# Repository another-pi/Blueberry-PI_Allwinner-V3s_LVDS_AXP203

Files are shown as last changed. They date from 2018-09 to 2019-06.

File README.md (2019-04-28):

main build board now is `Blueberry Pi 7.1.2.esp32.no-lan.gsm-a9g`. because `a9g` gsm module is much better then `sim800c`. because of open source SDK and support of GPS.

but still work-in-progress. not finished.

sources of Linux kernel (4.10.15) for this board(s). preconfigured:
https://github.com/bhgv/linux

precompiled Linux-4.10.15 SD-image with support of fb-graphics an resistive touch:
https://github.com/bhgv/linux/releases/tag/1.0a

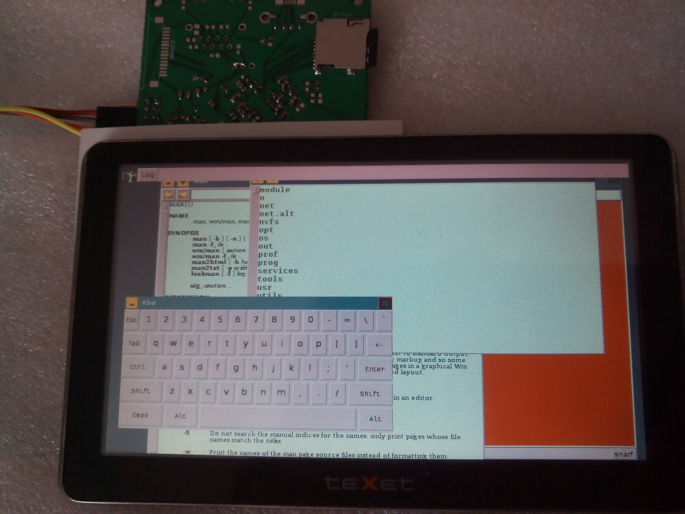
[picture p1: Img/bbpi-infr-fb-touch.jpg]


Blueberry Pi 7.1.2.esp32.no-lan
===============================
(not finished yet)
* removed lan port,
* added 50pins fpc RGB connector for popular 7" tfts (AT070TN[90, 91, 92, 93, 94]) in parallel to 40pins one,
* connector for capacitive touchscreens (i2c1),
* power converters for 50pins socket,
* 25% smaller board.
* esp32 now wired as wifi/bluetooth and as io expander-coprocessor.

Blueberry Pi 7.1.1+ESP32-S
==========================
(not finised yet)
* other power controller(s). 3 cheap and easy to solder chips in sot23-6,
* a try to use ESP32-S module as a WiFi/Bluetooth co-processor.

List of compatible (and cheap) LCDs (with touchscreens)
=======================================================
* ? 7" -- MDT7000
* 7" -- TKR7040B
* 7" -- GL070009T0-40

* 6" -- KD060G1-40nc-a5
* 6" -- TM060RDH02

* 5" -- HSD050IDW1-A20
* 5" -- MH0506D
* 5" -- KD50G21-40NT-A1
* 5" -- A26TF9C032169 * A0 -A20
* 5" -- H-H050L-12M
* 5" -- GL050001C0-40
* 5" -- ft050s800480005n-v01
* 5" -- HW800480F-0F-0L-20
* 5" -- hw800480f-0f-0l-10
* 5" -- T050SWV012T
* 5" -- T050SWV015T
* 5" -- FC050S151-01
* 5" -- KD50G23-40NB-A1
* 5" -- HLY050ML115-12A

(
* 6" -- texet tn-811bt

* 5" --
- Window N5 TOP Tablet PC/ N5PRO/ Onda 580
- TeXet T-939HD
- TeXet T-930HD
- TeXet TN-550A
- TeXet TN-511HD
- TeXet TN-521HD
- TeXet TN-610HD
- TeXet TN-611HD
- TeXet TM-650 (100%)
- Explay PN-955
- Explay PN-960
- SHTURMANN Play 500
- IQU Smile
- Lexand Si-515 Pro HD
- Lexand SG-615 PRO HD
- Ritmix
- EasyGo 500Bi (100%)
- lexand str-5350 hd (100%)
- Prestigio Geovision 5500BTFMHD (100%)
- Prestigio GeoVision 5600GPRSHD
- Explay SLK5
- JXD S5300
- TurboGames New
- EXEQ SET
)

Blueberry Pi 7.1+axp203
=======================
is the Blueberry Pi 7.1 board but with AXP203 power controller, not EA3036. and has DC-DC step down (5-12v) on power input.

Blueberry PI 7.1
================

Added:
------
* LVDS interface with cheap SN65LVDS84 serialiser,
* resistive touchscreen controller TSC2003 + pinheader for resistive touch,
* flash w25q128,
* more popular MicroSD card slot,
* datasheets for them

Removed:
--------
* pinheader for OV7670

Blueberry PI
============
Another fruit single board computer (SBC), based on the Allwinner V3s system on a chip (SOC).
The Allwinner V3s comes in an easy to solder 128pin TQFP package.

The Blueberry PI features:

- 100 mbps Ethernet
- 1 USB Host Port / 1 mini USB port
- MIPI CSI interface (unfortunately no support in the linux kernel yet)
- Pinheader for an OV2640 and an OV7670
- Wifi and bluetooth
- RGB interface for connecting displays
- Audio jack
- an onboard microphone
- four buttons for play, pause, next and previous
- a Raspberry PI compatible header
- SPI Flash
- SD card slot

The Blueberry PI can boot from an SD card or SPI Flash.
Since the V3s doesn't have a standard video output, I'm planning on creating a video addon board which provides VGA or HDMI. In combination with the ADV7611 it is possible to capture HDMI.

If you have any questions email me at marcel[dot]thuermer(at)smail[dot]emt[dot]h[minus]brs[dot]de

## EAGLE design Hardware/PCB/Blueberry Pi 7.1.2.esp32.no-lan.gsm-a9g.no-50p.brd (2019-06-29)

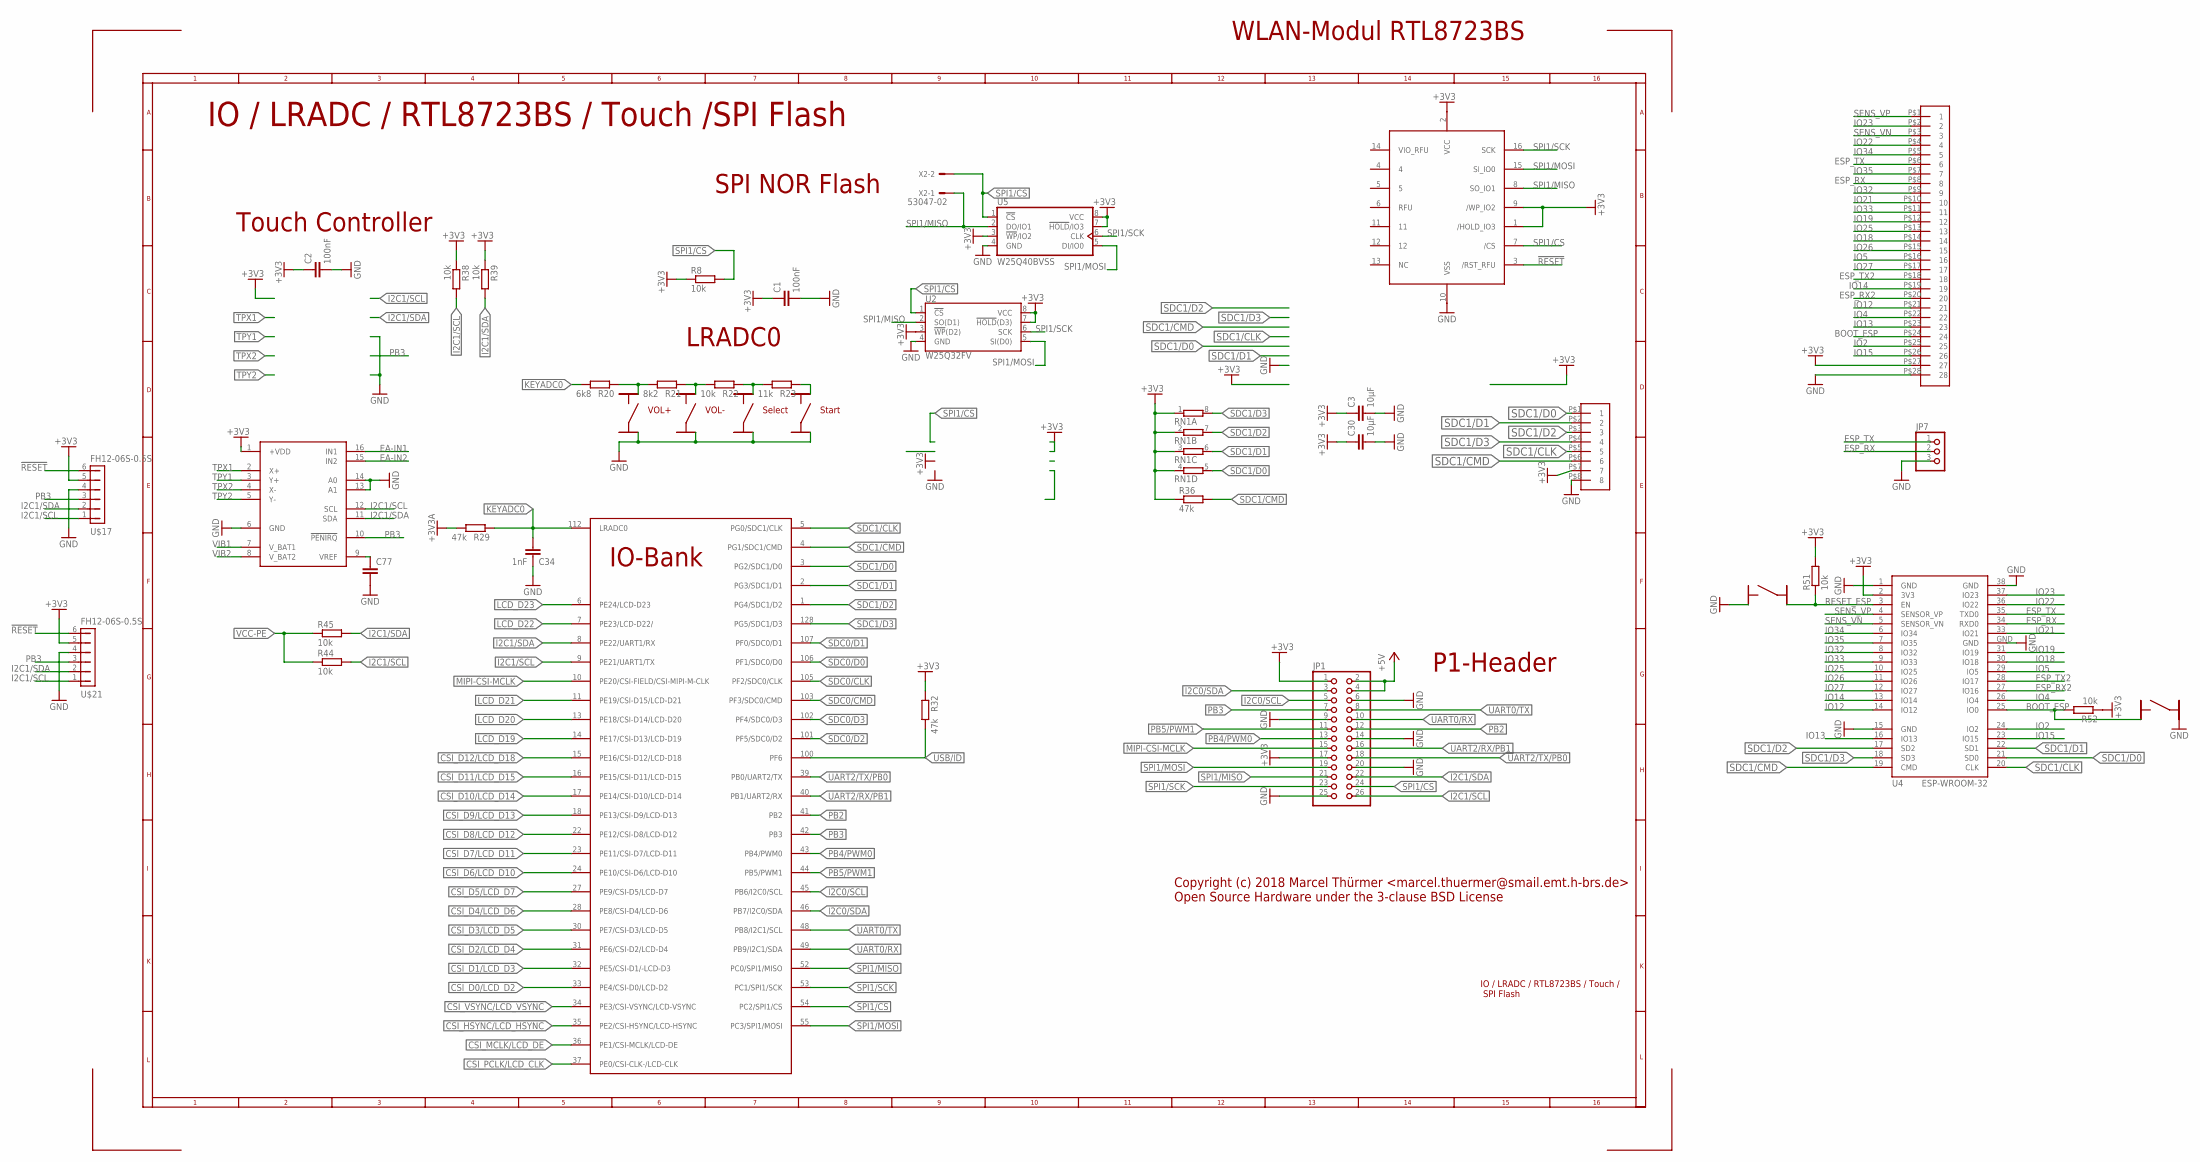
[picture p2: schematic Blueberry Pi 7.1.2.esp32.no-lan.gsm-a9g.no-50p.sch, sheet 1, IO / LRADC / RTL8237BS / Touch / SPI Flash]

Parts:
C1, C2: 100nF; C0603
C3, C30: 10µF; C0805
C34: 1nF; C0603
C77: C-EUC0603; C0603
JP1: PINHD-2X13; 2X13
JP7: PINHD-1X3M; 1X03M
R8, R22, R38, R39, R44, R45, R51, R52: 10k; R0603
R20: 6k8; R0603
R21: 8k2; R0603
R23: 11k; R0603
R29, R32, R36: 47k; R0603
RN1: 4R-NEXB38V; EXB38V
S-BOOT-ESP: BUTTON_3X3MM_4PINS; BUT_3X3_4PINS
S-RST-ESP: BUTTON_3X3MM_4PINS; BUT_3X3_4PINS
S-SEL: BUTTON_3X3MM_4PINS; BUT_3X3_4PINS
S-START: BUTTON_3X3MM_4PINS; BUT_3X3_4PINS
S-VOL+: BUTTON_3X3MM_4PINS; BUT_3X3_4PINS
S-VOL-: BUTTON_3X3MM_4PINS; BUT_3X3_4PINS
U2: W25Q32FV; WSON8-6X5MM
U4: ESP-WROOM-32
U5: W25Q40BVSS; SO08-SS
U$1: V3S; QFP-128
U$3: HDR-1.27MM-142; HDR-1.27MM-19*2
U$4: HDR-1.27MM-42; HDR-1.27MM-4*2
U$7: TSC2003; TSSOP16
U$16: S25FL256S; WSOIC-16
U$17, U$21: FH12-06S-0.5S; FH12-6S-0.5SH
X2: 53047-02

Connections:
!RESET: U$16.3 (/RST_RFU), U$17.6, U$21.6; also elsewhere on the board
+3V3: C1.1, C2.1, C3.1, C30.1, JP1.1, JP1.17, R8.1, R32.1, R36.1, R38.1, R39.1, R51.2, R52.1, RN1.1, RN1.2 (1), RN1.3 (1), RN1.4 (1), U2.3 (!WP!(D2)), U2.7 (!HOLD!(D3)), U2.8 (VCC), U4.2 (3V3), U5.3 (!WP!/IO2), U5.7 (!HOLD!/IO3), U5.8 (VCC), U$3.P$27 (27), U$4.P$7 (7), U$7.1 (+VDD), U$16.1 (/HOLD_IO3), U$16.2 (VCC), U$16.9 (/WP_IO2), U$17.5, U$21.5; also elsewhere on the board
+3V3A: R29.2; also elsewhere on the board
+5V: JP1.2, JP1.4; also elsewhere on the board
BOOT_ESP: R52.2, S-BOOT-ESP.P$1, U4.25 (IO0), U$3.P$24 (24)
CSI_D0/LCD_D2: U$1.33 (PE4/CSI-D0/LCD-D2); also elsewhere on the board
CSI_D1/LCD_D3: U$1.32 (PE5/CSI-D1/-LCD-D3); also elsewhere on the board
CSI_D2/LCD_D4: U$1.31 (PE6/CSI-D2/LCD-D4); also elsewhere on the board
CSI_D3/LCD_D5: U$1.30 (PE7/CSI-D3/LCD-D5); also elsewhere on the board
CSI_D4/LCD_D6: U$1.28 (PE8/CSI-D4/LCD-D6); also elsewhere on the board
CSI_D5/LCD_D7: U$1.27 (PE9/CSI-D5/LCD-D7); also elsewhere on the board
CSI_D6/LCD_D10: U$1.24 (PE10/CSI-D6/LCD-D10); also elsewhere on the board
CSI_D7/LCD_D11: U$1.23 (PE11/CSI-D7/LCD-D11); also elsewhere on the board
CSI_D8/LCD_D12: U$1.22 (PE12/CSI-D8/LCD-D12); also elsewhere on the board
CSI_D9/LCD_D13: U$1.18 (PE13/CSI-D9/LCD-D13); also elsewhere on the board
CSI_D10/LCD_D14: U$1.17 (PE14/CSI-D10/LCD-D14); also elsewhere on the board
CSI_D11/LCD_D15: U$1.16 (PE15/CSI-D11/LCD-D15); also elsewhere on the board
CSI_D12/LCD_D18: U$1.15 (PE16/CSI-D12/LCD-D18); also elsewhere on the board
CSI_HSYNC/LCD_HSYNC: U$1.35 (PE2/CSI-HSYNC/LCD-HSYNC); also elsewhere on the board
CSI_MCLK/LCD_DE: U$1.36 (PE1/CSI-MCLK/LCD-DE); also elsewhere on the board
CSI_PCLK/LCD_CLK: U$1.37 (PE0/CSI-CLK-/LCD-CLK); also elsewhere on the board
CSI_VSYNC/LCD_VSYNC: U$1.34 (PE3/CSI-VSYNC/LCD-VSYNC); also elsewhere on the board
EA-IN1: U$7.16 (IN1); also elsewhere on the board
EA-IN2: U$7.15 (IN2); also elsewhere on the board
ESP_RX: JP7.2, U4.34 (RXD0), U$3.P$8 (8)
ESP_RX2: U4.27 (IO16), U$3.P$20 (20); also elsewhere on the board
ESP_TX: JP7.1, U4.35 (TXD0), U$3.P$6 (6)
ESP_TX2: U4.28 (IO17), U$3.P$18 (18); also elsewhere on the board
GND: C1.2, C2.2, C3.2, C30.2, C34.1, C77.2, JP1.6, JP1.9, JP1.14, JP1.20, JP1.25, JP7.3, S-BOOT-ESP.P$2, S-RST-ESP.P$1, S-SEL.P$4, S-START.P$4, S-VOL+.P$4, S-VOL-.P$4, U2.4 (GND), U4.1 (GND), U4.15 (GND), U4.38 (GND), U4.GND, U5.4 (GND), U$3.P$28 (28), U$4.P$8 (8), U$7.6 (GND), U$7.13 (A1), U$7.14 (A0), U$16.10 (VSS), U$17.4, U$21.4; also elsewhere on the board
I2C0/SCL: JP1.5, U$1.45 (PB6/I2C0/SCL)
I2C0/SDA: JP1.3, U$1.46 (PB7/I2C0/SDA)
I2C1/SCL: JP1.26, R38.2, R44.2, U$1.9 (PE21/UART1/TX), U$7.12 (SCL), U$17.1, U$21.1; also elsewhere on the board
I2C1/SDA: JP1.22, R39.2, R45.2, U$1.8 (PE22/UART1/RX), U$7.11 (SDA), U$17.2, U$21.2; also elsewhere on the board
IO2: U4.24 (IO2), U$3.P$25 (25)
IO4: U4.26 (IO4), U$3.P$22 (22)
IO5: U4.29 (IO5), U$3.P$16 (16)
IO12: U4.14 (IO12), U$3.P$21 (21)
IO13: U4.16 (IO13), U$3.P$23 (23)
IO14: U4.13 (IO14), U$3.P$19 (19); also elsewhere on the board
IO15: U4.23 (IO15), U$3.P$26 (26)
IO18: U4.30 (IO18), U$3.P$14 (14)
IO19: U4.31 (IO19), U$3.P$12 (12)
IO21: U4.33 (IO21), U$3.P$10 (10)
IO22: U4.36 (IO22), U$3.P$4 (4)
IO23: U4.37 (IO23), U$3.P$2 (2)
IO25: U4.10 (IO25), U$3.P$13 (13)
IO26: U4.11 (IO26), U$3.P$15 (15)
IO27: U4.12 (IO27), U$3.P$17 (17); also elsewhere on the board
IO32: U4.8 (IO32), U$3.P$9 (9)
IO33: U4.9 (IO33), U$3.P$11 (11)
IO34: U4.6 (IO34), U$3.P$5 (5)
IO35: U4.7 (IO35), U$3.P$7 (7)
KEYADC0: C34.2, R20.2, R29.1, U$1.112 (LRADC0)
LCD_D19: U$1.14 (PE17/CSI-D13/LCD-D19); also elsewhere on the board
LCD_D20: U$1.13 (PE18/CSI-D14/LCD-D20); also elsewhere on the board
LCD_D21: U$1.11 (PE19/CSI-D15/LCD-D21); also elsewhere on the board
LCD_D22: U$1.7 (PE23/LCD-D22/); also elsewhere on the board
LCD_D23: U$1.6 (PE24/LCD-D23); also elsewhere on the board
MIPI-CSI-MCLK: JP1.15, U$1.10 (PE20/CSI-FIELD/CSI-MIPI-M-CLK); also elsewhere on the board
unnamed: R20.1, R21.2, S-VOL+.P$3
unnamed: C77.1, U$7.9 (VREF)
unnamed: R21.1, R22.2, S-VOL-.P$3
unnamed: R22.1, R23.2, S-SEL.P$3
unnamed: R23.1, S-START.P$3
PB2: JP1.12, U$1.41 (PB2); also elsewhere on the board
PB3: JP1.7, U$1.42 (PB3), U$7.10 (!PENIRQ), U$17.3, U$21.3; also elsewhere on the board
PB4/PWM0: JP1.13, U$1.43 (PB4/PWM0); also elsewhere on the board
PB5/PWM1: JP1.11, U$1.44 (PB5/PWM1); also elsewhere on the board
RESET_ESP: R51.1, S-RST-ESP.P$2, U4.3 (EN)
SDC0/CLK: U$1.105 (PF2/SDC0/CLK); also elsewhere on the board
SDC0/CMD: U$1.103 (PF3/SDC0/CMD); also elsewhere on the board
SDC0/D0: U$1.106 (PF1/SDC0/D0); also elsewhere on the board
SDC0/D1: U$1.107 (PF0/SDC0/D1); also elsewhere on the board
SDC0/D2: U$1.101 (PF5/SDC0/D2); also elsewhere on the board
SDC0/D3: U$1.102 (PF4/SDC0/D3); also elsewhere on the board
SDC1/CLK: U4.20 (CLK), U$1.5 (PG0/SDC1/CLK), U$4.P$5 (5)
SDC1/CMD: R36.2, U4.19 (CMD), U$1.4 (PG1/SDC1/CMD), U$4.P$6 (6)
SDC1/D0: RN1.5 (2), U4.21 (SD0), U$1.3 (PG2/SDC1/D0), U$4.P$1 (1)
SDC1/D1: RN1.6 (2), U4.22 (SD1), U$1.2 (PG3/SDC1/D1), U$4.P$2 (2)
SDC1/D2: RN1.7 (2), U4.17 (SD2), U$1.1 (PG4/SDC1/D2), U$4.P$3 (3)
SDC1/D3: RN1.8 (2), U4.18 (SD3), U$1.128 (PG5/SDC1/D3), U$4.P$4 (4)
SENS_VN: U4.5 (SENSOR_VN), U$3.P$3 (3)
SENS_VP: U4.4 (SENSOR_VP), U$3.P$1 (1)
SPI1/CS: JP1.24, R8.2, U2.1 (!CS!), U5.1 (!CS!), U$1.54 (PC2/SPI1/CS), U$16.7 (/CS), X2.2
SPI1/MISO: JP1.21, U2.2 (SO(D1)), U5.2 (DO/IO1), U$1.52 (PC0/SPI1/MISO), U$16.8 (SO_IO1), X2.1
SPI1/MOSI: JP1.19, U2.5 (SI(D0)), U5.5 (DI/IO0), U$1.55 (PC3/SPI1/MOSI), U$16.15 (SI_IO0)
SPI1/SCK: JP1.23, U2.6 (SCK), U5.6 (CLK), U$1.53 (PC1/SPI1/SCK), U$16.16 (SCK)
TPX1: U$7.2 (X+); also elsewhere on the board
TPX2: U$7.4 (X-); also elsewhere on the board
TPY1: U$7.3 (Y+); also elsewhere on the board
TPY2: U$7.5 (Y-); also elsewhere on the board
UART0/RX: JP1.10, U$1.49 (PB9/I2C1/SDA)
UART0/TX: JP1.8, U$1.48 (PB8/I2C1/SCL)
UART2/RX/PB1: JP1.16, U$1.40 (PB1/UART2/RX); also elsewhere on the board
UART2/TX/PB0: JP1.18, U$1.39 (PB0/UART2/TX); also elsewhere on the board
USB/ID: R32.2, U$1.100 (PF6); also elsewhere on the board
VCC-PE: R44.1, R45.1
VIB1: U$7.7 (V_BAT1); also elsewhere on the board
VIB2: U$7.8 (V_BAT2); also elsewhere on the board

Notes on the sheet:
IO / LRADC / RTL8723BS / Touch / SPI Flash
Copyright (c) 2018 Marcel Thürmer <marcel.thuermer@smail.emt.h-brs.de> Open Source Hardware under the 3-clause BSD License
SPI NOR Flash
WLAN-Modul RTL8723BS
P1-Header
LRADC0
Start
Select
VOL-
VOL+
Touch Controller
IO / LRADC / RTL8723BS / Touch /SPI Flash

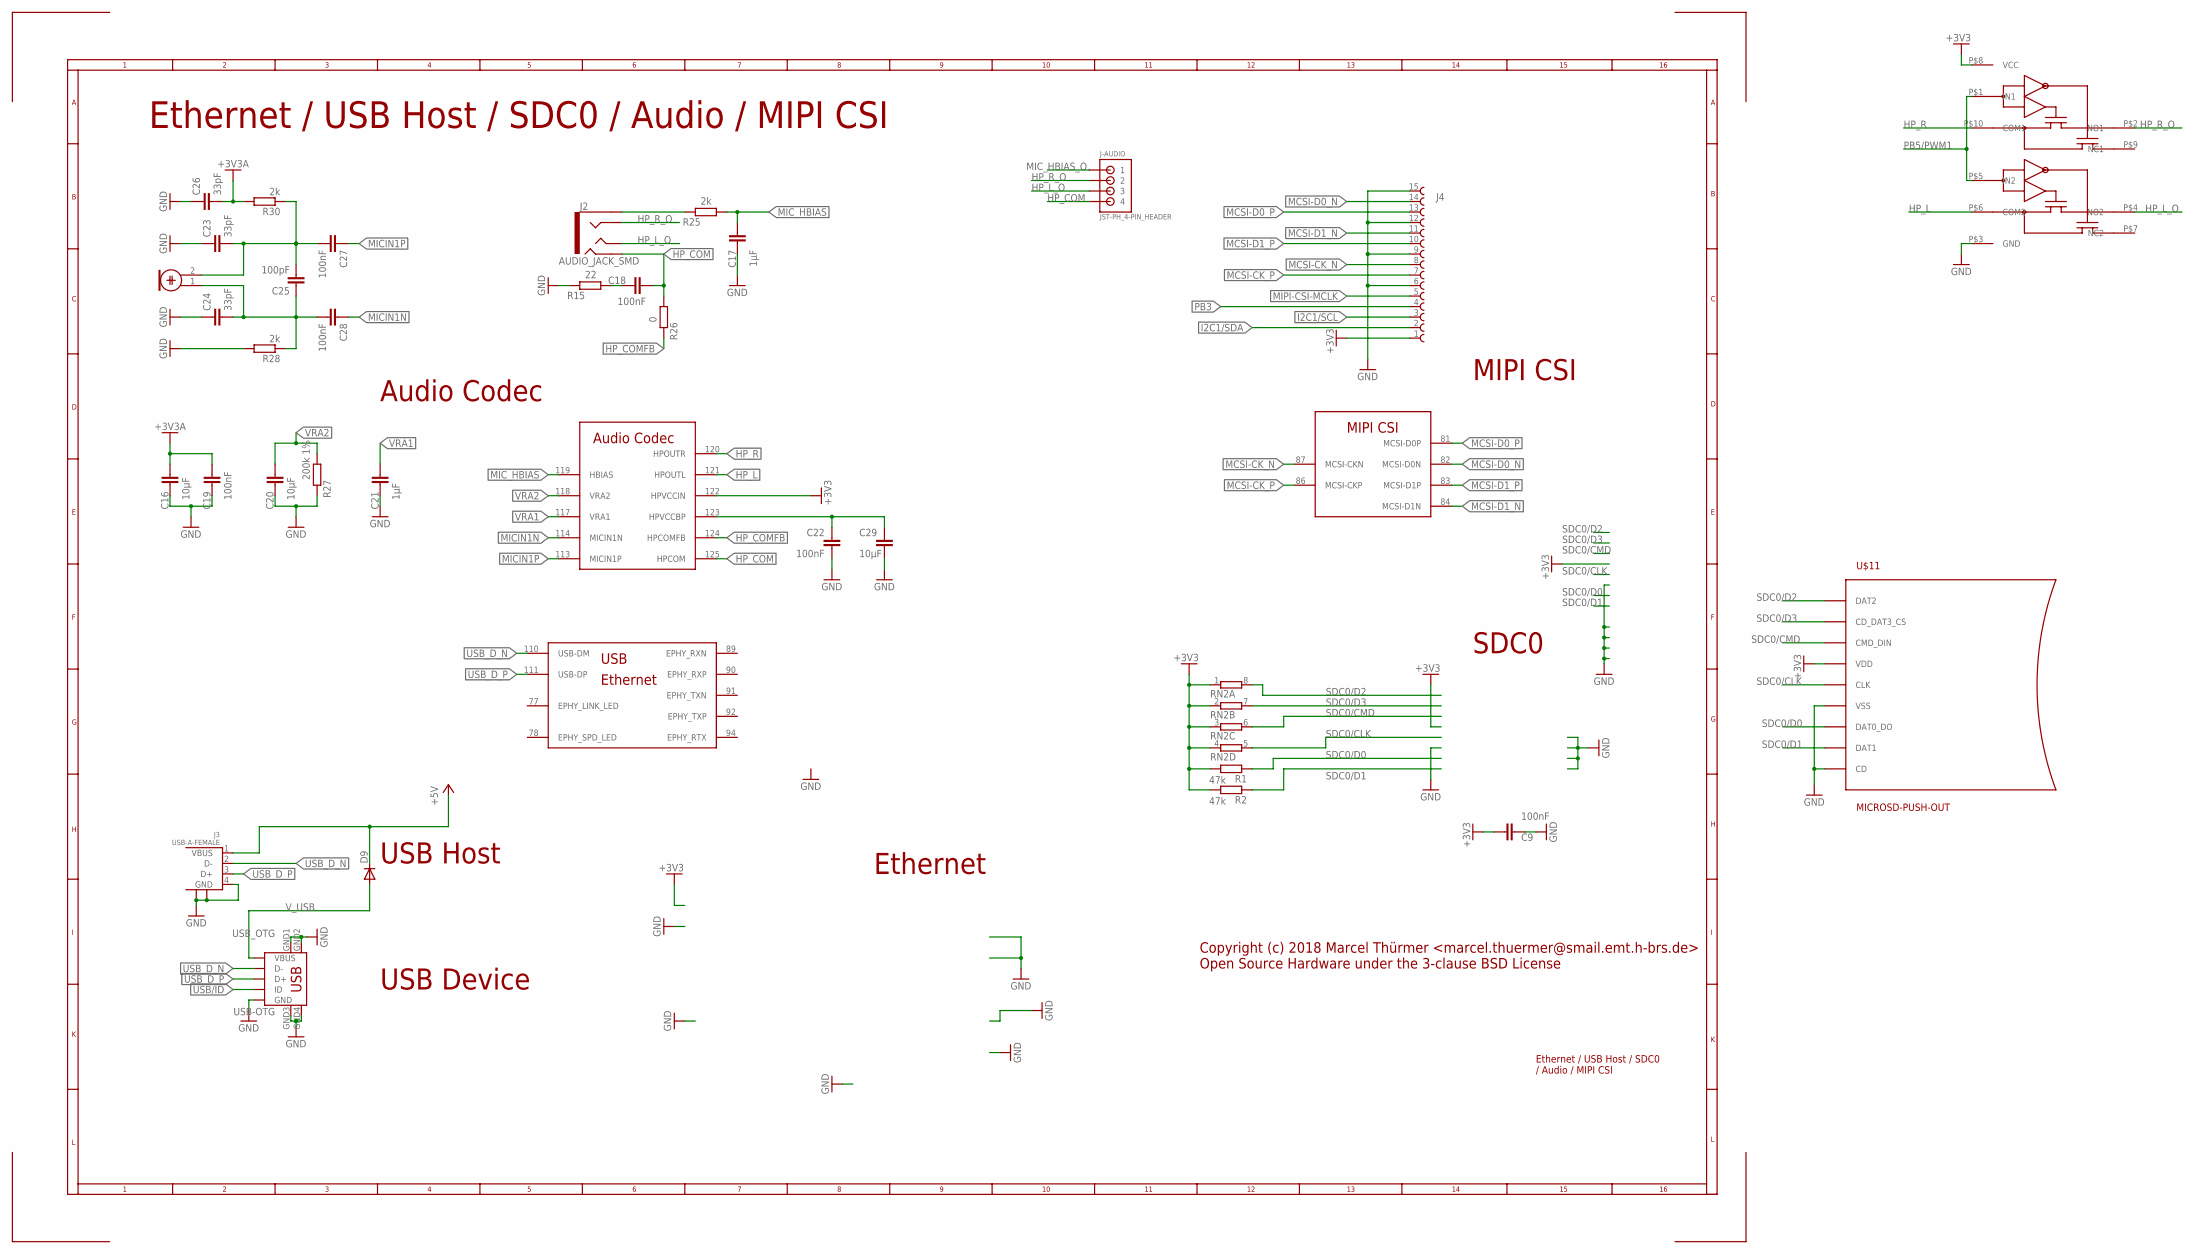
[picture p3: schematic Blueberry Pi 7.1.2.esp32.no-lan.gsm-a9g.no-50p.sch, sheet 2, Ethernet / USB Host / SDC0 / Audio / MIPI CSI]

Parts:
C9, C18, C19, C22, C27, C28: 100nF; C0603
C16, C20, C29: 10µF; C0805
C17, C21: 1µF; C0603
C23, C24, C26: 33pF; C0603
C25: 100pF; C0603
D9: DIODE-SOD323-W; SOD323-W
J2: AUDIO_JACK_SMD; AUDIO_JACK_3.5MM_TRRS_SMD_RA
J3: USB-A-FEMALE
J4: 68611514122
J-AUDIO: JST-PH_4-PIN_HEADER; JST_B4B-PH_HEADER
MIC: ELECTRET_MICROPHON-F6035AP; F6035AP
R1, R2: 47k; R0603
R15: 22; R0603
R25, R28, R30: 2k; R0603
R26: 0; R0603
R27: 200k 1%; R0603
RN2: 4R-NEXB38V; EXB38V
U$1: V3S; QFP-128
U$11: MICROSD-PUSH-OUT
U$24: TS5A23157
USB_OTG: USB-OTG; USB_MINI_9PIN

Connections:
+3V3: C9.1, J4.1 (15), R1.2, R2.2, RN2.1, RN2.2 (1), RN2.3 (1), RN2.4 (1), U$1.122 (HPVCCIN), U$11.4 (VDD), U$24.P$8 (VCC); also elsewhere on the board
+3V3A: C16.2, C19.2, C26.2, R30.2; also elsewhere on the board
+5V: D9.C, J3.1 (VBUS); also elsewhere on the board
GND: C9.2, C16.1, C17.2, C19.1, C20.1, C21.1, C22.2, C23.1, C24.1, C26.1, C29.1, J3.4 (GND), J3.P$1, J3.P$2, J4.6 (10), J4.9 (7), J4.12 (4), J4.15 (1), R15.1, R27.1, R28.2, U$11.6 (VSS), U$11.CD, U$11.G1 (VSS), U$11.G2 (VSS), U$11.G3 (VSS), U$11.G4 (VSS), U$24.P$3 (GND), USB_OTG.GND, USB_OTG.GND1, USB_OTG.GND2, USB_OTG.GND3, USB_OTG.GND4; also elsewhere on the board
HP_COM: C18.2, J2.RING2, J-AUDIO.P4 (4), R26.2, U$1.125 (HPCOM)
HP_COMFB: R26.1, U$1.124 (HPCOMFB)
HP_L: U$1.121 (HPOUTL), U$24.P$6 (COM2)
HP_L_O: J2.TIP, J-AUDIO.P3 (3), U$24.P$4 (NO2)
HP_R: U$1.120 (HPOUTR), U$24.P$10 (COM1); also elsewhere on the board
HP_R_O: J2.RING1, J-AUDIO.P2 (2), U$24.P$2 (NO1)
I2C1/SCL: J4.3 (13); also elsewhere on the board
I2C1/SDA: J4.2 (14); also elsewhere on the board
MCSI-CK_N: J4.8, U$1.87 (MCSI-CKN)
MCSI-CK_P: J4.7 (9), U$1.86 (MCSI-CKP)
MCSI-D0_N: J4.14 (2), U$1.82 (MCSI-D0N)
MCSI-D0_P: J4.13 (3), U$1.81 (MCSI-D0P)
MCSI-D1_N: J4.11 (5), U$1.84 (MCSI-D1N)
MCSI-D1_P: J4.10 (6), U$1.83 (MCSI-D1P)
MICIN1N: C28.1, U$1.114 (MICIN1N)
MICIN1P: C27.1, U$1.113 (MICIN1P); also elsewhere on the board
MIC_HBIAS: C17.1, R25.2, U$1.119 (HBIAS)
MIC_HBIAS_O: J2.EARTH, J-AUDIO.P1 (1), R25.1
MIPI-CSI-MCLK: J4.5 (11); also elsewhere on the board
unnamed: C22.1, C29.2, U$1.123 (HPVCCBP)
unnamed: C18.1, R15.2
unnamed: C23.2, C25.2, C27.2, MIC.2, R30.1
unnamed: C24.2, C25.1, C28.2, MIC.1, R28.1
PB3: J4.4 (12); also elsewhere on the board
PB5/PWM1: U$24.P$1 (IN1), U$24.P$5 (IN2); also elsewhere on the board
SDC0/CLK: RN2.5 (2), U$11.5 (CLK); also elsewhere on the board
SDC0/CMD: RN2.6 (2), U$11.3 (CMD_DIN); also elsewhere on the board
SDC0/D0: R1.1, U$11.7 (DAT0_DO); also elsewhere on the board
SDC0/D1: R2.1, U$11.8 (DAT1); also elsewhere on the board
SDC0/D2: RN2.8 (2), U$11.1 (DAT2); also elsewhere on the board
SDC0/D3: RN2.7 (2), U$11.2 (CD_DAT3_CS); also elsewhere on the board
USB/ID: USB_OTG.ID; also elsewhere on the board
USB_D_N: J3.2 (D-), U$1.110 (USB-DM), USB_OTG.D-
USB_D_P: J3.3 (D+), U$1.111 (USB-DP), USB_OTG.D+
VRA1: C21.2, U$1.117 (VRA1)
VRA2: C20.2, R27.2, U$1.118 (VRA2)
V_USB: D9.A, USB_OTG.VBUS; also elsewhere on the board

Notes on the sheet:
Ethernet / USB Host / SDC0 / Audio / MIPI CSI
USB Host
Audio Codec
MIPI CSI
Ethernet
SDC0
Copyright (c) 2018 Marcel Thürmer <marcel.thuermer@smail.emt.h-brs.de> Open Source Hardware under the 3-clause BSD License
USB Device
Ethernet / USB Host / SDC0 / Audio / MIPI CSI

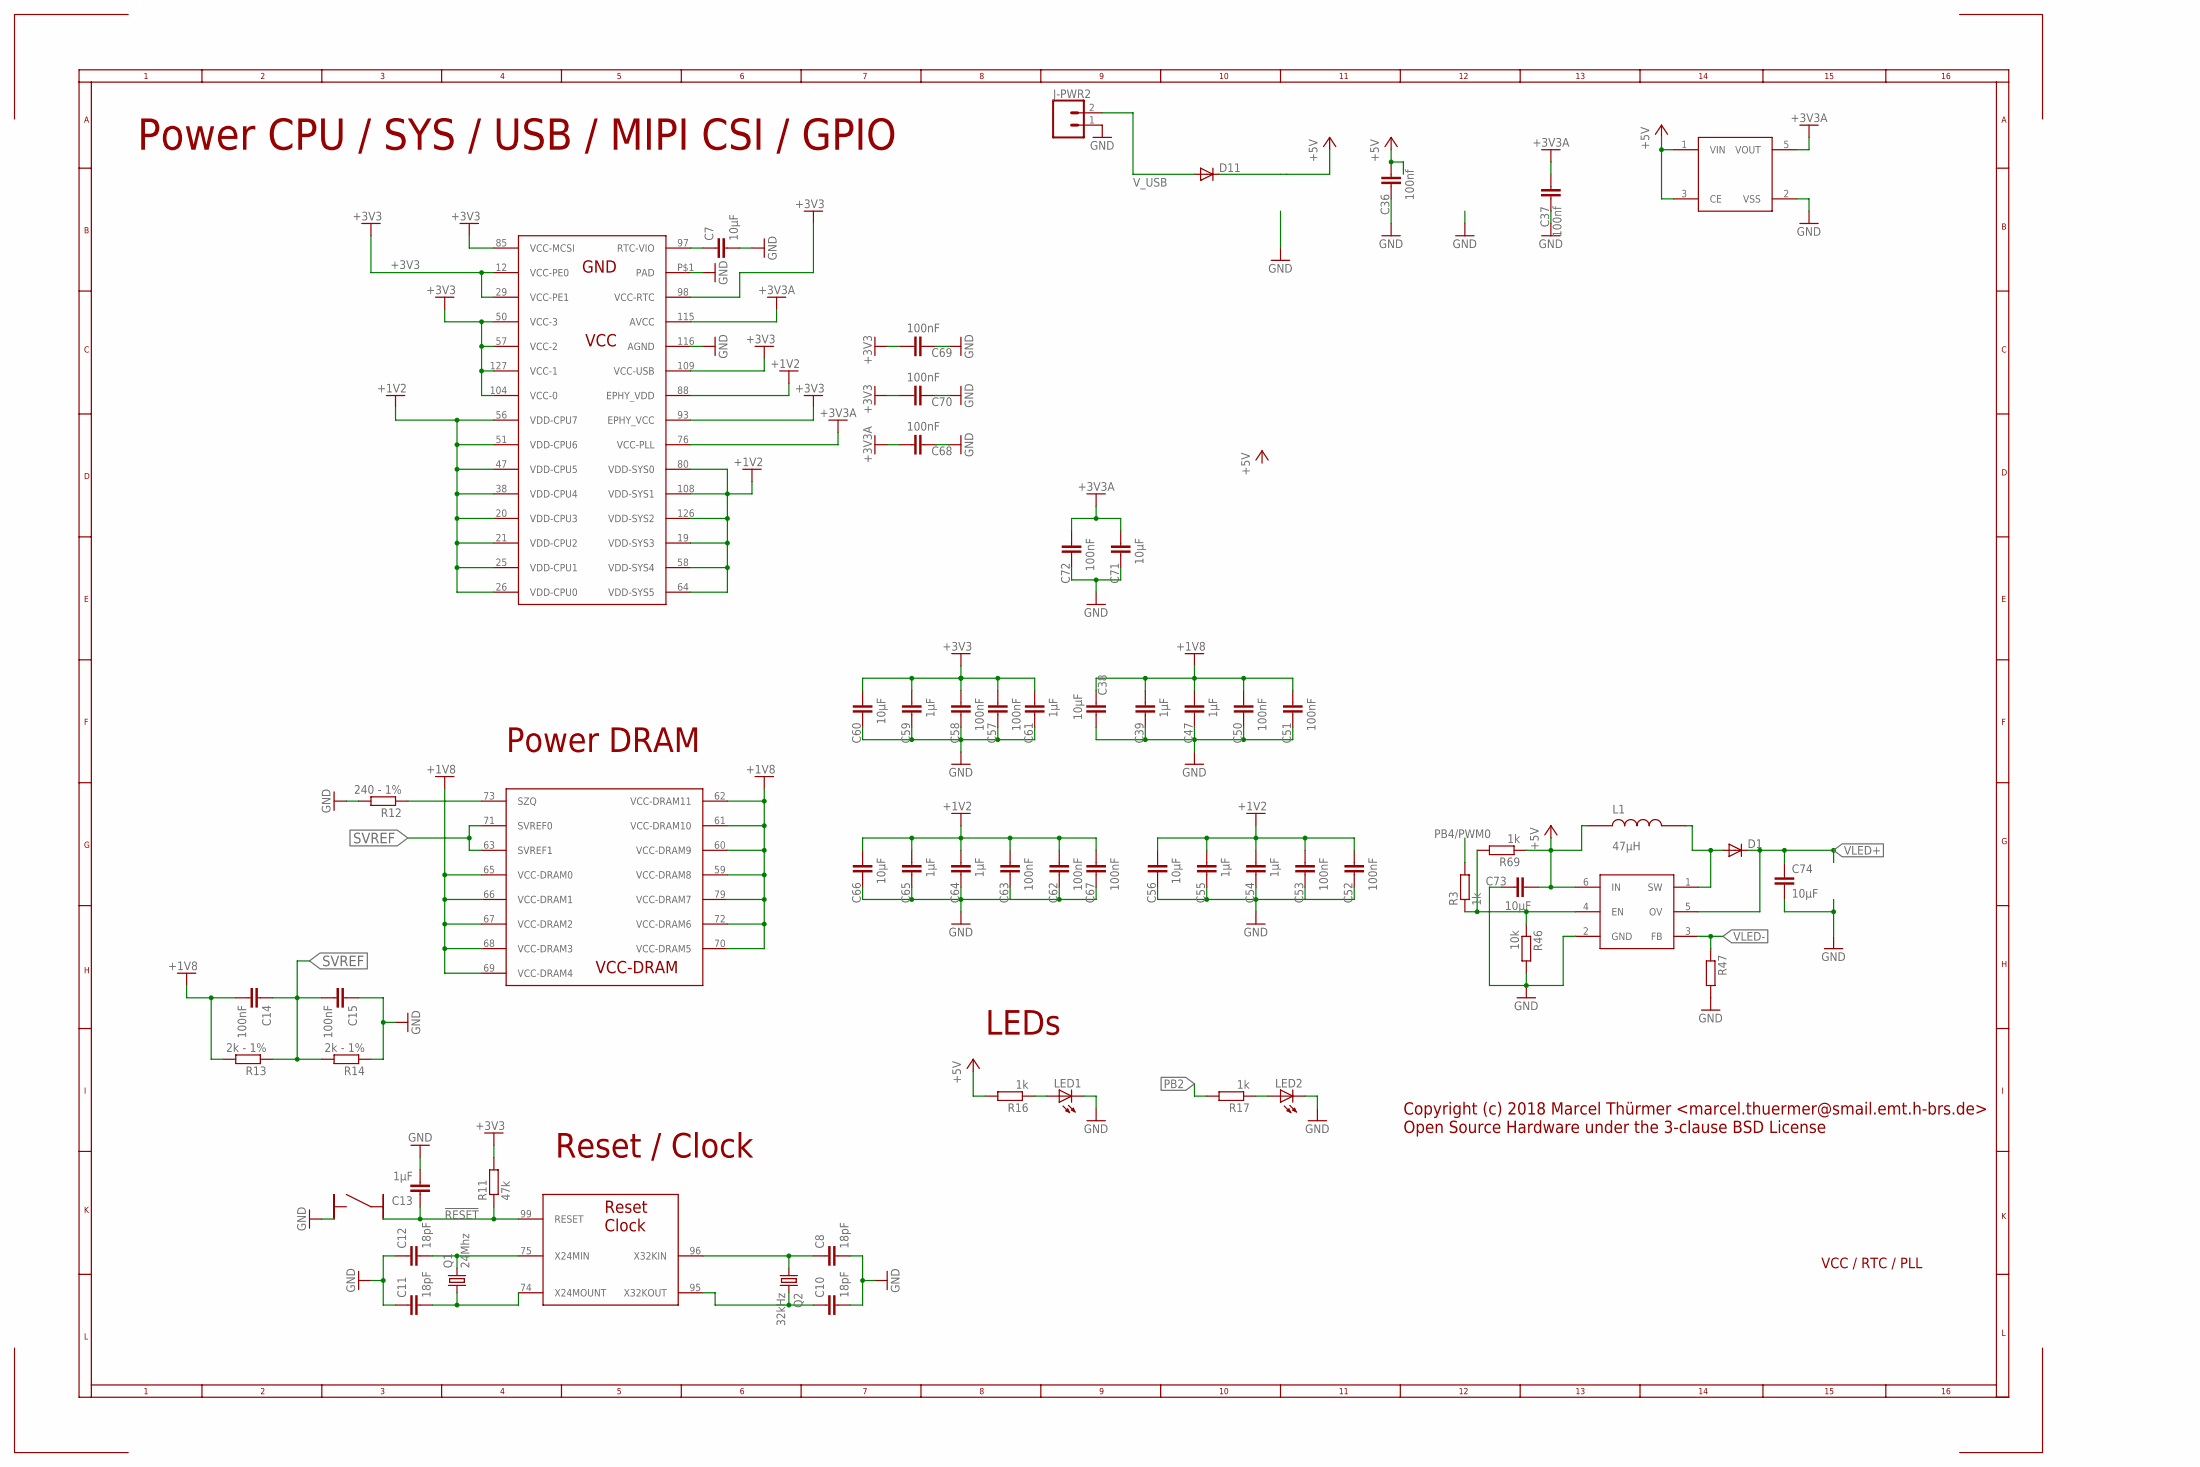
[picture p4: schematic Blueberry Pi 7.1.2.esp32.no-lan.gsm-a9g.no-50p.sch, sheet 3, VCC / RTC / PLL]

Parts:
C7, C38, C56, C60, C66, C71, C73, C74: 10µF; C0805
C8, C10, C11, C12: 18pF; C0603
C13, C39, C47, C54, C55, C59, C61, C64, C65: 1µF; C0603
C14, C15, C50, C51, C52, C53, C57, C58, C62, C63, C67, C68, C69, C70, C72: 100nF; C0603
C36, C37: 100nf; C0603
D1, D11: DIODE-SOD323-W; SOD323-W
J-PWR2: CONN_02; 1X02
L1: 47µH; CD32
LED1, LED2: LEDCHIPLED_0805; CHIPLED_0805
Q1: 24Mhz; HC49U-V
Q2: 32kHz; TC38H
R3, R16, R17, R69: 1k; R0603
R11: 47k; R0603
R12: 240 - 1%; R0603
R13, R14: 2k - 1%; R0603
R46: 10k; R0603
R47: R-EU_R0603; R0603
S-RST: BUTTON_3X3MM_4PINS; BUT_3X3_4PINS
U$1: V3S; QFP-128
U$9: PT4101; SOT23-6
U$15: XC6204; SOT25

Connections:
!RESET: C13.1, R11.1, S-RST.P$2, U$1.99 (RESET); also elsewhere on the board
+1V2: C52.1, C53.1, C54.1, C55.1, C56.1, C62.1, C63.1, C64.1, C65.1, C66.1, C67.1, U$1.19 (VDD-SYS3), U$1.20 (VDD-CPU3), U$1.21 (VDD-CPU2), U$1.25 (VDD-CPU1), U$1.26 (VDD-CPU0), U$1.38 (VDD-CPU4), U$1.47 (VDD-CPU5), U$1.51 (VDD-CPU6), U$1.56 (VDD-CPU7), U$1.58 (VDD-SYS4), U$1.64 (VDD-SYS5), U$1.80 (VDD-SYS0), U$1.88 (EPHY_VDD), U$1.108 (VDD-SYS1), U$1.126 (VDD-SYS2); also elsewhere on the board
+1V8: C14.2, C38.2, C39.1, C47.1, C50.1, C51.1, R13.2, U$1.59 (VCC-DRAM8), U$1.60 (VCC-DRAM9), U$1.61 (VCC-DRAM10), U$1.62 (VCC-DRAM11), U$1.65 (VCC-DRAM0), U$1.66 (VCC-DRAM1), U$1.67 (VCC-DRAM2), U$1.68 (VCC-DRAM3), U$1.69 (VCC-DRAM4), U$1.70 (VCC-DRAM5), U$1.72 (VCC-DRAM6), U$1.79 (VCC-DRAM7); also elsewhere on the board
+3V3: C57.1, C58.1, C59.1, C60.1, C61.1, C69.1, C70.1, R11.2, U$1.12 (VCC-PE0), U$1.29 (VCC-PE1), U$1.50 (VCC-3), U$1.57 (VCC-2), U$1.85 (VCC-MCSI), U$1.93 (EPHY_VCC), U$1.98 (VCC-RTC), U$1.104 (VCC-0), U$1.109 (VCC-USB), U$1.127 (VCC-1); also elsewhere on the board
+3V3A: C37.1, C68.1, C71.1, C72.1, U$1.76 (VCC-PLL), U$1.115 (AVCC), U$15.5 (VOUT); also elsewhere on the board
+5V: C36.1, C73.1, D11.C, L1.P$1, R16.2, R69.1, U$9.6 (IN), U$15.1 (VIN), U$15.3 (CE); also elsewhere on the board
GND: C7.2, C8.2, C10.2, C11.1, C12.1, C13.2, C15.1, C36.2, C37.2, C38.1, C39.2, C47.2, C50.2, C51.2, C52.2, C53.2, C54.2, C55.2, C56.2, C57.2, C58.2, C59.2, C60.2, C61.2, C62.2, C63.2, C64.2, C65.2, C66.2, C67.2, C68.2, C69.2, C70.2, C71.2, C72.2, C73.2, C74.2, J-PWR2.1, LED1.C, LED2.C, R12.2, R14.1, R46.2, R47.2, S-RST.P$1, U$1.116 (AGND), U$1.P$1 (PAD), U$9.2 (GND), U$15.2 (VSS); also elsewhere on the board
unnamed: LED1.A, R16.1
unnamed: LED2.A, R17.1
unnamed: R3.1, R46.1, R69.2, U$9.4 (EN)
unnamed: D1.A, L1.P$2, U$9.1 (SW)
unnamed: C7.1, U$1.97 (RTC-VIO)
unnamed: C10.1, Q2.2, U$1.95 (X32KOUT)
unnamed: C8.1, Q2.1, U$1.96 (X32KIN)
unnamed: C11.2, Q1.1, U$1.74 (X24MOUNT)
unnamed: C12.2, Q1.2, U$1.75 (X24MIN)
unnamed: R12.1, U$1.73 (SZQ)
PB2: R17.2; also elsewhere on the board
PB4/PWM0: R3.2; also elsewhere on the board
SVREF: C14.1, C15.2, R13.1, R14.2, U$1.63 (SVREF1), U$1.71 (SVREF0)
VLED+: C74.1, D1.C, U$9.5 (OV); also elsewhere on the board
VLED-: R47.1, U$9.3 (FB); also elsewhere on the board
V_USB: D11.A, J-PWR2.2; also elsewhere on the board

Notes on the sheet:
VCC / RTC / PLL
Power CPU / SYS / USB / MIPI CSI / GPIO
Power DRAM
Copyright (c) 2018 Marcel Thürmer <marcel.thuermer@smail.emt.h-brs.de> Open Source Hardware under the 3-clause BSD License
Reset / Clock
LEDs

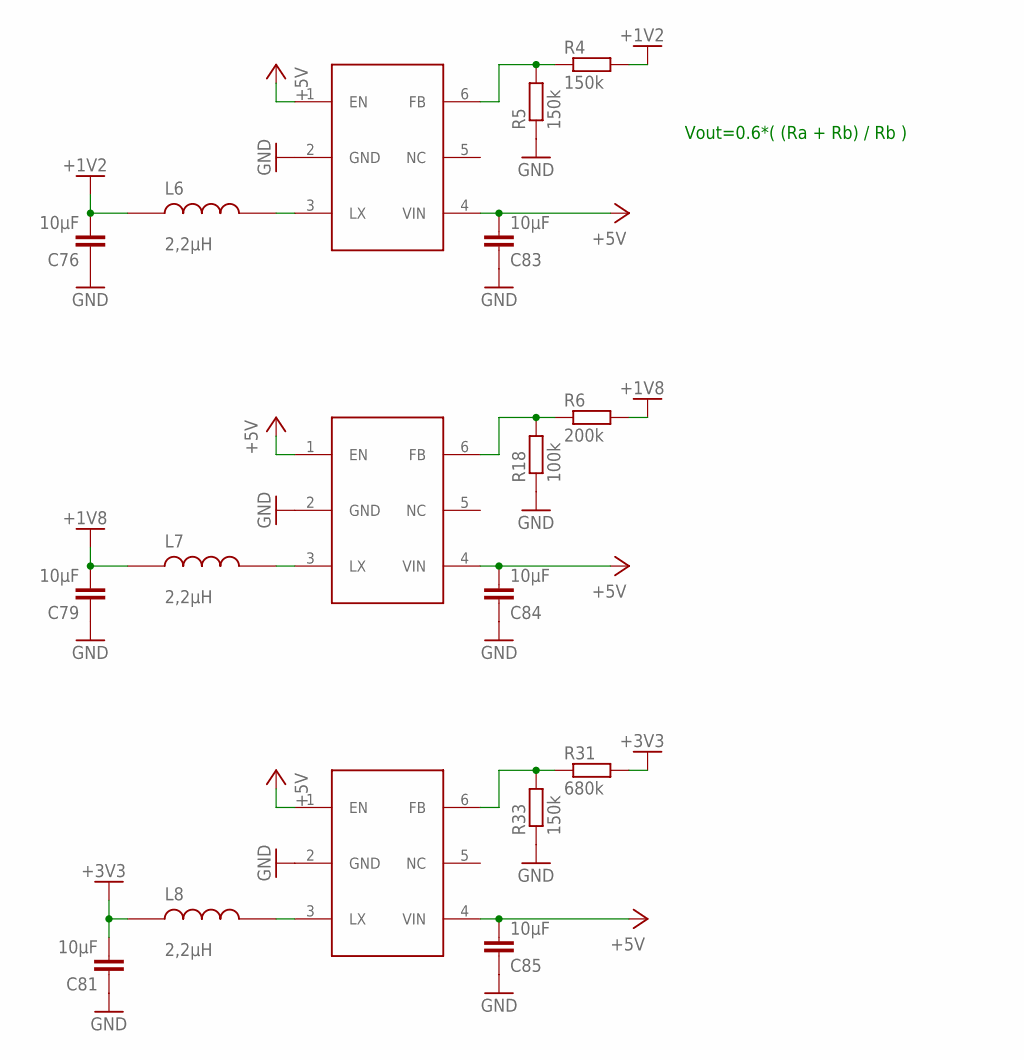
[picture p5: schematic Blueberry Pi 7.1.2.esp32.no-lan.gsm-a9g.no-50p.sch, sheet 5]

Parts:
C76, C79, C81, C83, C84, C85: 10µF; C0805
L6, L7, L8: 2,2µH; CD32
R4, R5, R33: 150k; R0603
R6: 200k; R0603
R18: 100k; R0603
R31: 680k; R0603
U$5, U$12, U$13: STI3411; SOT23-6

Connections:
+1V2: C76.2, L6.P$1, R4.2; also elsewhere on the board
+1V8: C79.2, L7.P$1, R6.2; also elsewhere on the board
+3V3: C81.2, L8.P$1, R31.2; also elsewhere on the board
+5V: C83.2, C84.2, C85.2, U$5.1 (EN), U$5.4 (VIN), U$12.1 (EN), U$12.4 (VIN), U$13.1 (EN), U$13.4 (VIN); also elsewhere on the board
GND: C76.1, C79.1, C81.1, C83.1, C84.1, C85.1, R5.1, R18.1, R33.1, U$5.2 (GND), U$12.2 (GND), U$13.2 (GND); also elsewhere on the board
unnamed: L6.P$2, U$13.3 (LX)
unnamed: L7.P$2, U$5.3 (LX)
unnamed: R4.1, R5.2, U$13.6 (FB)
unnamed: L8.P$2, U$12.3 (LX)
unnamed: R6.1, R18.2, U$5.6 (FB)
unnamed: R31.1, R33.2, U$12.6 (FB)

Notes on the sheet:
Vout=0.6*( (Ra + Rb) / Rb )

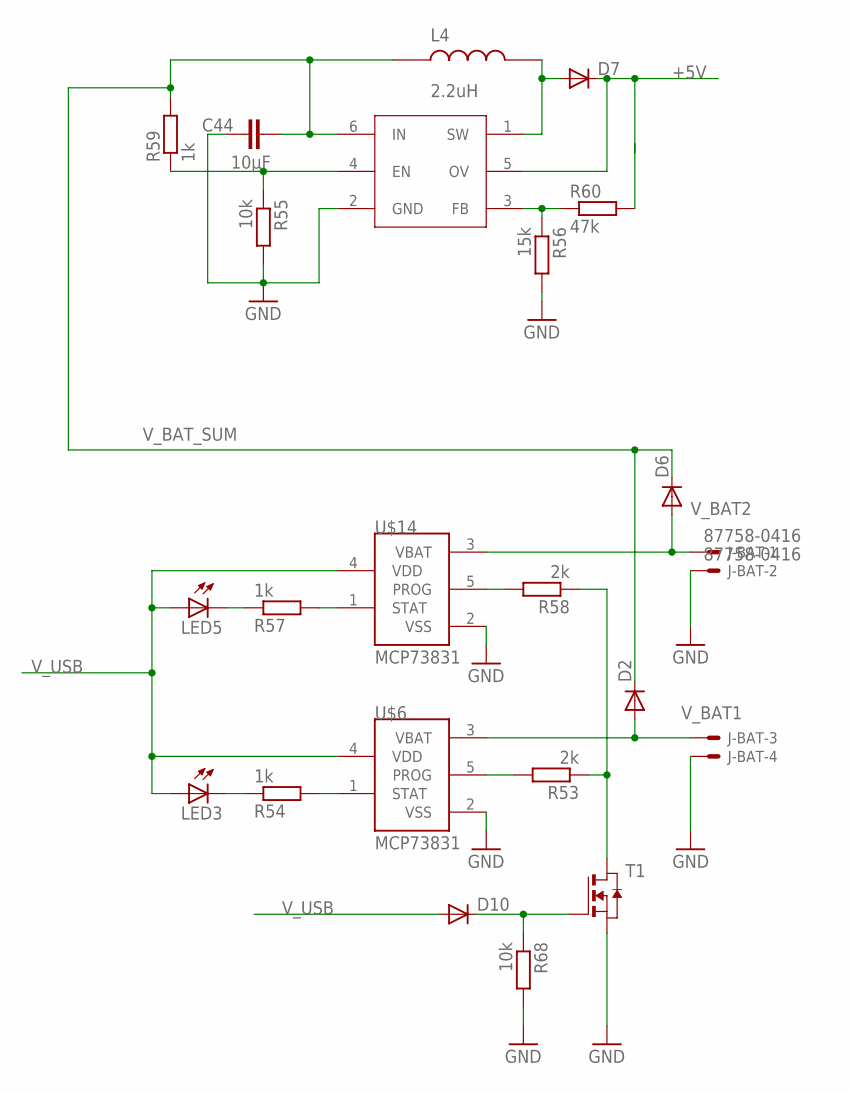
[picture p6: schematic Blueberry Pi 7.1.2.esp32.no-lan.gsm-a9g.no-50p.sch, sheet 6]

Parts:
C44: 10µF; C0805
D2, D6: DIODE-DO214AC; DO214AC
D7, D10: DIODE-SOD323-W; SOD323-W
J-BAT: 87758-0416
L4: 2.2uH; CD32
LED3, LED5: LEDCHIPLED_0805; CHIPLED_0805
R53, R58: 2k; R0603
R54, R57, R59: 1k; R0603
R55, R68: 10k; R0603
R56: 15k; R0603
R60: 47k; R0603
T1: NMOSSOT23; SOT-23
U$6, U$14: MCP73831; SOT23-5L
U$10: PT4101; SOT23-6

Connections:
+5V: D7.C, R60.2, U$10.5 (OV); also elsewhere on the board
GND: C44.2, J-BAT.2, J-BAT.4, R55.2, R56.2, R68.2, T1.2 (S), U$6.2 (VSS), U$10.2 (GND), U$14.2 (VSS); also elsewhere on the board
unnamed: R53.1, R58.1, T1.1 (D)
unnamed: R56.1, R60.1, U$10.3 (FB)
unnamed: R55.1, R59.1, U$10.4 (EN)
unnamed: D7.A, L4.P$2, U$10.1 (SW)
unnamed: D10.C, R68.1, T1.3 (G)
unnamed: R53.2, U$6.5 (PROG)
unnamed: LED3.C, R54.1
unnamed: R54.2, U$6.1 (STAT)
unnamed: R58.2, U$14.5 (PROG)
unnamed: R57.2, U$14.1 (STAT)
unnamed: LED5.C, R57.1
V_BAT1: D2.A, J-BAT.3, U$6.3 (VBAT)
V_BAT2: D6.A, J-BAT.1, U$14.3 (VBAT)
V_BAT_SUM: C44.1, D2.C, D6.C, L4.P$1, R59.2, U$10.6 (IN); also elsewhere on the board
V_USB: D10.A, LED3.A, LED5.A, U$6.4 (VDD), U$14.4 (VDD); also elsewhere on the board

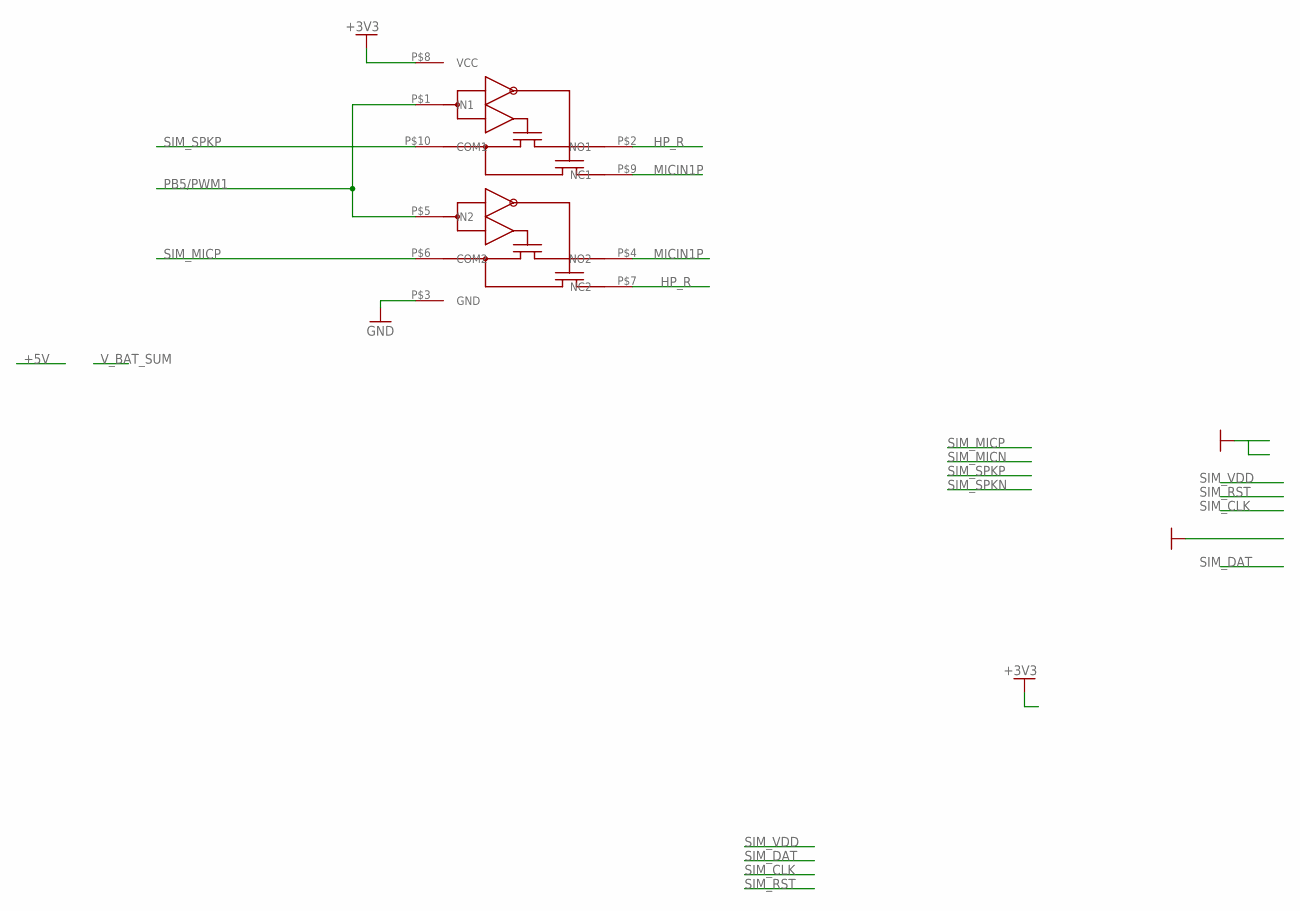
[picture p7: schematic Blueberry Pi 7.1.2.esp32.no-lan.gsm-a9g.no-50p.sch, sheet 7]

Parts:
U$19: TS5A23157

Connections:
+3V3: U$19.P$8 (VCC); also elsewhere on the board
GND: U$19.P$3 (GND); also elsewhere on the board
HP_R: U$19.P$2 (NO1), U$19.P$7 (NC2); also elsewhere on the board
MICIN1P: U$19.P$4 (NO2), U$19.P$9 (NC1); also elsewhere on the board
PB5/PWM1: U$19.P$1 (IN1), U$19.P$5 (IN2); also elsewhere on the board
SIM_MICP: U$19.P$6 (COM2); also elsewhere on the board
SIM_SPKP: U$19.P$10 (COM1); also elsewhere on the board

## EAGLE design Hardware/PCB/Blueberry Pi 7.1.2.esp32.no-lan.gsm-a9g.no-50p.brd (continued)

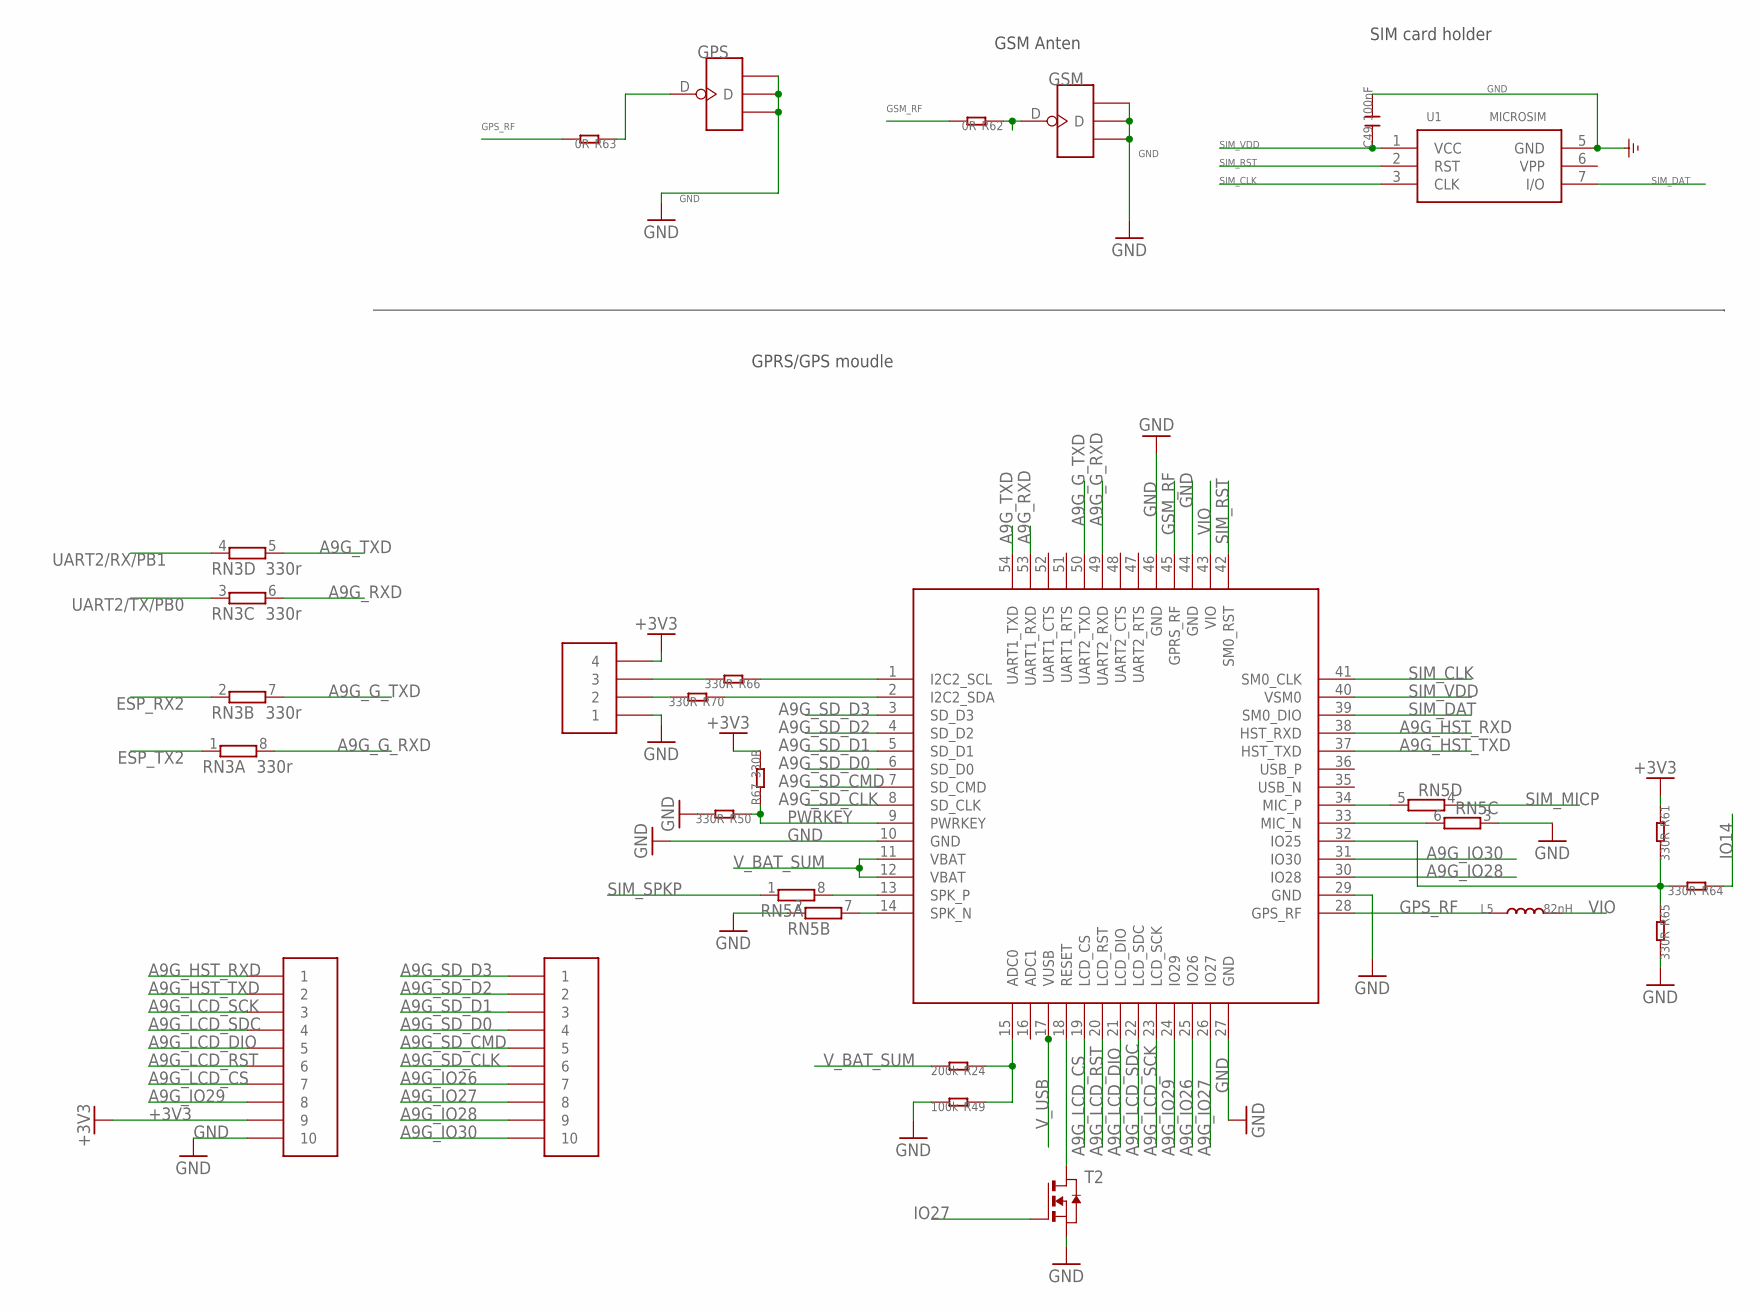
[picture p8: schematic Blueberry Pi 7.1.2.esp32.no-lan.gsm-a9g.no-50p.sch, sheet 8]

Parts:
C49: 100nF; C0603
DBG-COM1, DBG-COM2: HDR-1.27MM-110; HDR-1.27MM-1*10
GPS: ANTENNA-U-FL; 4P-U-FL
GSM: ANTENNA-U-FL; 4P-U-FL
L5: 82nH; L0603
R24: 200k; R0603
R49: 100k; R0603
R50, R61, R64, R65, R66, R67, R70: 330R; R0603
R62, R63: 0R; R0603
RN3: 330r; EXB38V
RN5: 4R-NEXB38V; EXB38V
T2: NMOSSOT23; SOT-23
U1: MICROSIM
U6: A9G
U$20: HDR-1.27MM-14; HDR-1.27MM-1*4

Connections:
+3V3: DBG-COM1.P$9 (9), R61.1, R67.2, U$20.P$4 (4); also elsewhere on the board
A9G_G_RXD: RN3.8 (2), U6.49 (UART2_RXD)
A9G_G_TXD: RN3.7 (2), U6.50 (UART2_TXD)
A9G_HST_RXD: DBG-COM1.P$1 (1), U6.38 (HST_RXD)
A9G_HST_TXD: DBG-COM1.P$2 (2), U6.37 (HST_TXD)
A9G_IO26: DBG-COM2.P$7 (7), U6.25 (IO26)
A9G_IO27: DBG-COM2.P$8 (8), U6.26 (IO27)
A9G_IO28: DBG-COM2.P$9 (9), U6.30 (IO28)
A9G_IO29: DBG-COM1.P$8 (8), U6.24 (IO29)
A9G_IO30: DBG-COM2.P$10 (10), U6.31 (IO30)
A9G_LCD_CS: DBG-COM1.P$7 (7), U6.19 (LCD_CS)
A9G_LCD_DIO: DBG-COM1.P$5 (5), U6.21 (LCD_DIO)
A9G_LCD_RST: DBG-COM1.P$6 (6), U6.20 (LCD_RST)
A9G_LCD_SCK: DBG-COM1.P$3 (3), U6.23 (LCD_SCK)
A9G_LCD_SDC: DBG-COM1.P$4 (4), U6.22 (LCD_SDC)
A9G_RXD: RN3.6 (2), U6.53 (UART1_RXD)
A9G_SD_CLK: DBG-COM2.P$6 (6), U6.8 (SD_CLK)
A9G_SD_CMD: DBG-COM2.P$5 (5), U6.7 (SD_CMD)
A9G_SD_D0: DBG-COM2.P$4 (4), U6.6 (SD_D0)
A9G_SD_D1: DBG-COM2.P$3 (3), U6.5 (SD_D1)
A9G_SD_D2: DBG-COM2.P$2 (2), U6.4 (SD_D2)
A9G_SD_D3: DBG-COM2.P$1 (1), U6.3 (SD_D3)
A9G_TXD: RN3.5 (2), U6.54 (UART1_TXD)
ESP_RX2: RN3.2 (1); also elsewhere on the board
ESP_TX2: RN3.1; also elsewhere on the board
GND: C49.2, DBG-COM1.P$10 (10), GPS.GND1, GPS.GND2, GPS.GND3, GSM.GND1, GSM.GND2, GSM.GND3, R49.2, R50.2, R65.2, RN5.2 (1), RN5.3 (1), T2.2 (S), U1.5 (GND), U6.10 (GND), U6.27 (GND), U6.29 (GND), U6.44 (GND), U6.46 (GND), U$20.P$1 (1); also elsewhere on the board
GPS_RF: L5.1, R63.2, U6.28 (GPS_RF)
GSM_RF: R62.2, U6.45 (GPRS_RF)
IO14: R64.1; also elsewhere on the board
IO27: T2.3 (G); also elsewhere on the board
unnamed: R24.1, R49.1, U6.15 (ADC0)
unnamed: RN5.6 (2), U6.33 (MIC_N)
unnamed: RN5.7 (2), U6.14 (SPK_N)
unnamed: R61.2, R64.2, R65.1, U6.32 (IO25)
unnamed: T2.1 (D), U6.18 (RESET)
unnamed: RN5.8 (2), U6.13 (SPK_P)
unnamed: R66.1, U6.1 (I2C2_SCL)
unnamed: GSM.D, R62.1
unnamed: GPS.D, R63.1
unnamed: R70.2, U$20.P$2 (2)
unnamed: R70.1, U6.2 (I2C2_SDA)
unnamed: RN5.5 (2), U6.34 (MIC_P)
unnamed: R66.2, U$20.P$3 (3)
PWRKEY: R50.1, R67.1, U6.9 (PWRKEY)
SIM_CLK: U1.3 (CLK), U6.41 (SM0_CLK)
SIM_DAT: U1.7 (I/O), U6.39 (SM0_DIO)
SIM_MICP: RN5.4 (1); also elsewhere on the board
SIM_RST: U1.2 (RST), U6.42 (SM0_RST)
SIM_SPKP: RN5.1; also elsewhere on the board
SIM_VDD: C49.1, U1.1 (VCC), U6.40 (VSM0)
UART2/RX/PB1: RN3.4 (1); also elsewhere on the board
UART2/TX/PB0: RN3.3 (1); also elsewhere on the board
VIO: L5.2, U6.43 (VIO)
V_BAT_SUM: R24.2, U6.11 (VBAT), U6.12 (VBAT); also elsewhere on the board
V_USB: U6.17 (VUSB); also elsewhere on the board

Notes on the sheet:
SIM card holder
GSM Anten
GPRS/GPS moudle

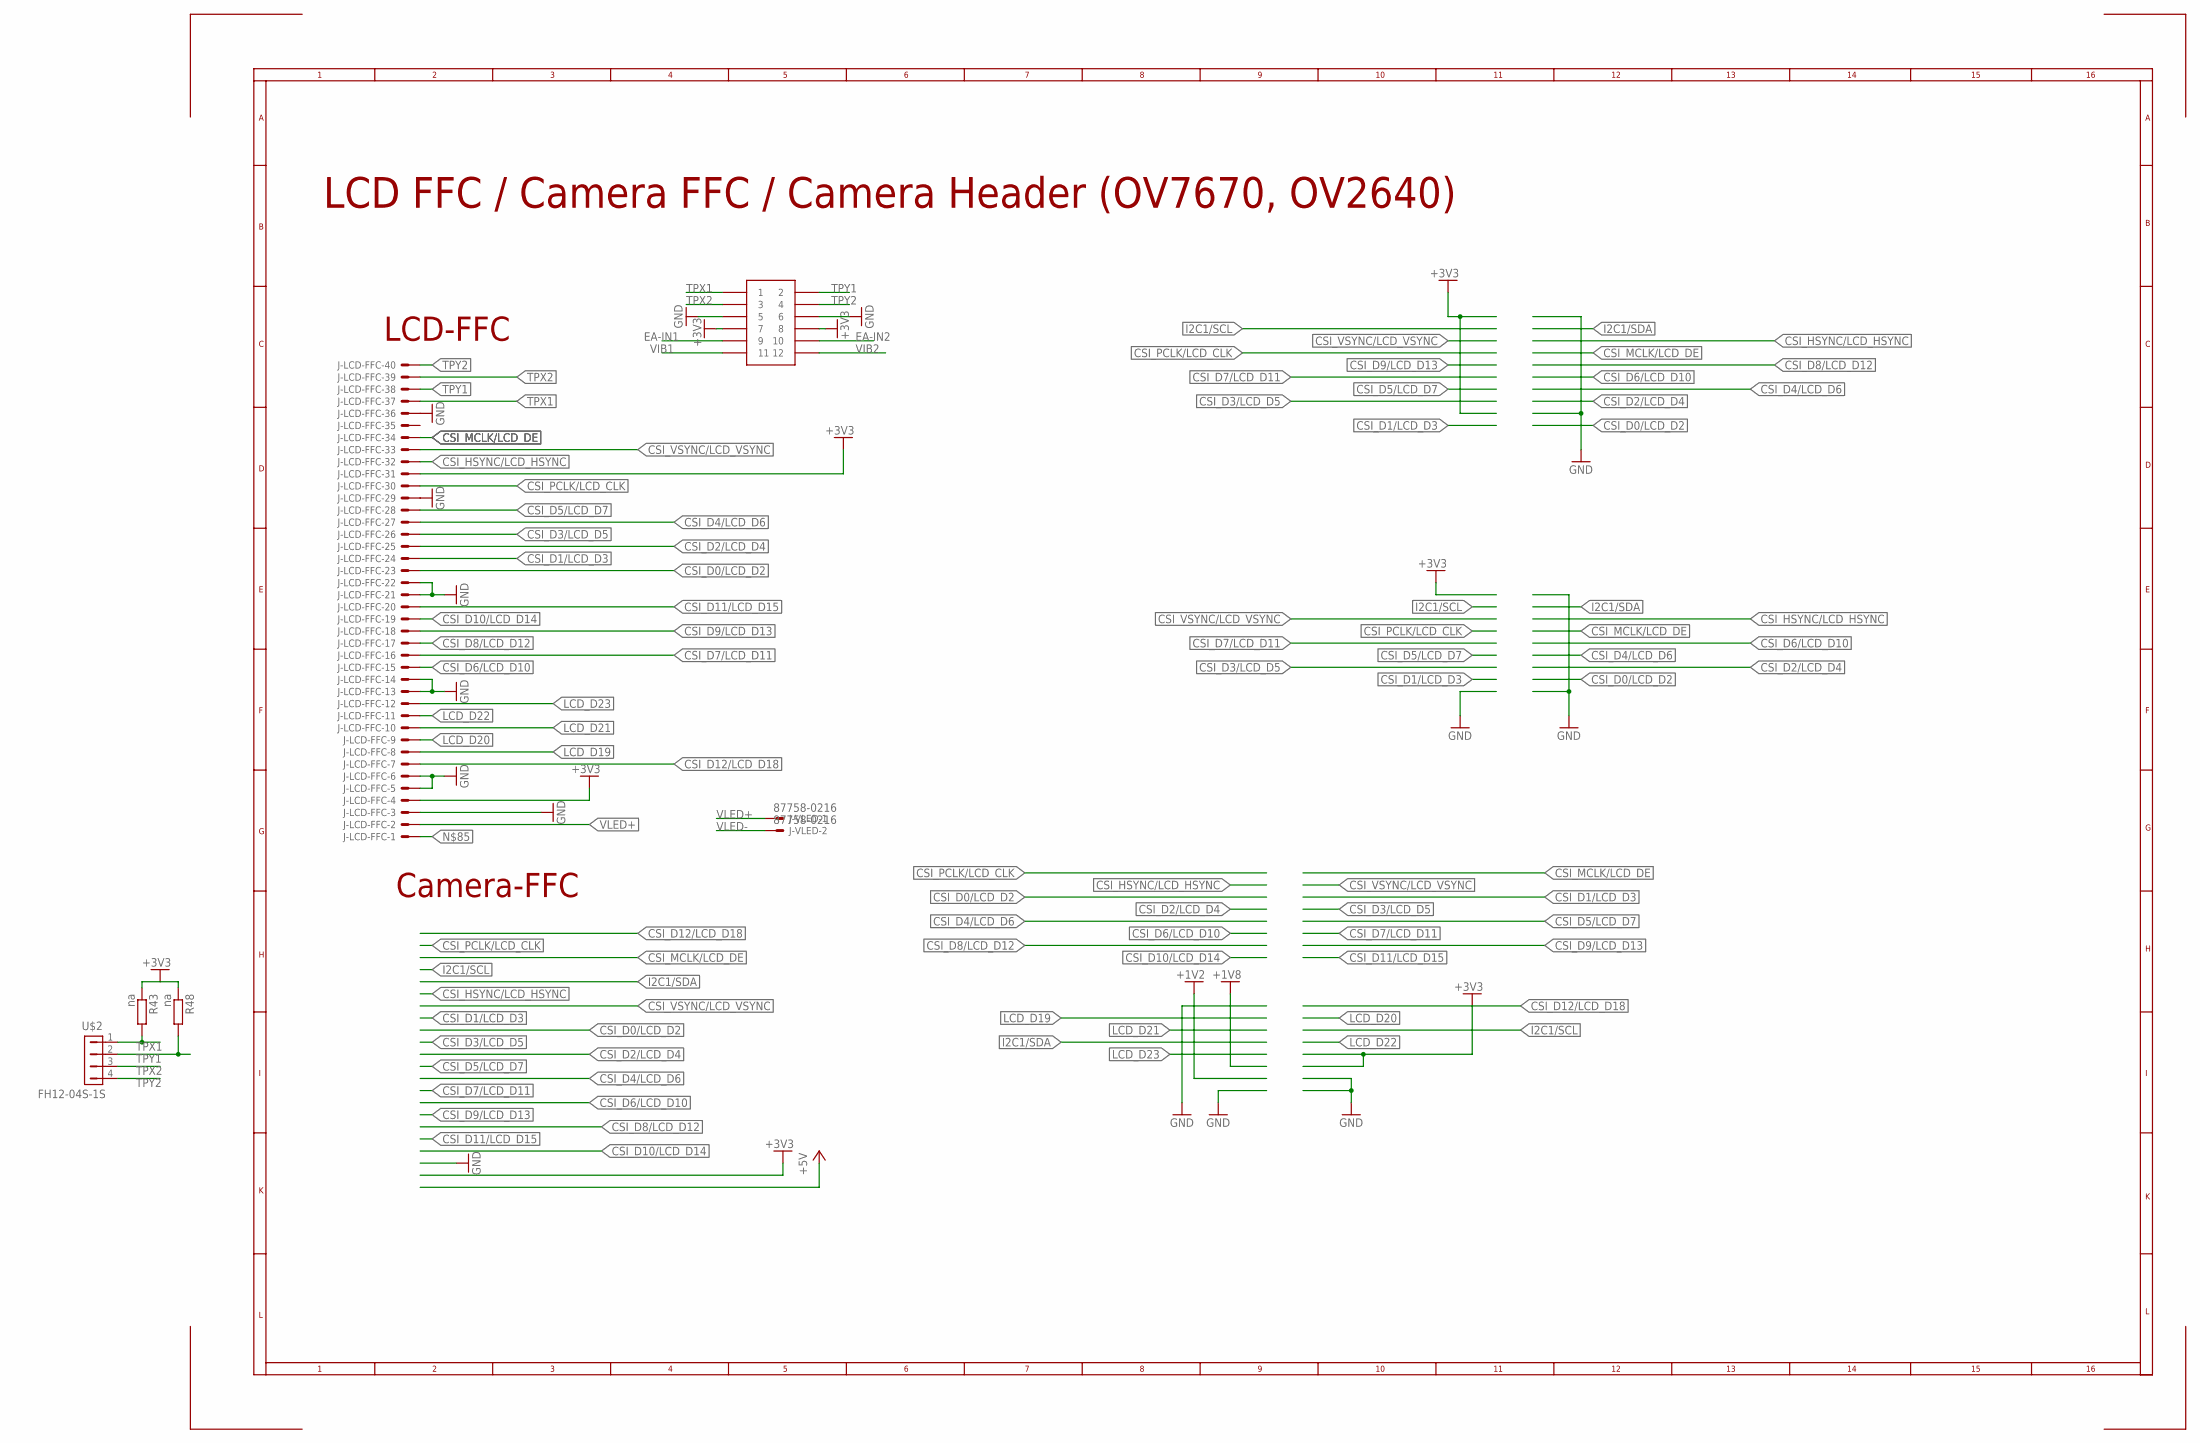
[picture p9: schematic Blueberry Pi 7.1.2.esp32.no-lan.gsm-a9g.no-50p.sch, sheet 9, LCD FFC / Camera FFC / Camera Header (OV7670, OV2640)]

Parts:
J-LCD-FFC: 40PINFPCH15-1LW; XF2H-4015-1LW
J-VLED: 87758-0216
R43, R48: na; R0603
U$2: FH12-04S-1S; FH12-04S-1SH
U$18: HDR-1.27MM-62; HDR-1.27MM-6*2

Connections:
+3V3: J-LCD-FFC.4 (MS), J-LCD-FFC.31 (MS), R43.1, R48.1, U$18.P$7 (7), U$18.P$8 (8); also elsewhere on the board
CSI_D0/LCD_D2: J-LCD-FFC.23 (MS); also elsewhere on the board
CSI_D1/LCD_D3: J-LCD-FFC.24 (MS); also elsewhere on the board
CSI_D2/LCD_D4: J-LCD-FFC.25 (MS); also elsewhere on the board
CSI_D3/LCD_D5: J-LCD-FFC.26 (MS); also elsewhere on the board
CSI_D4/LCD_D6: J-LCD-FFC.27 (MS); also elsewhere on the board
CSI_D5/LCD_D7: J-LCD-FFC.28 (MS); also elsewhere on the board
CSI_D6/LCD_D10: J-LCD-FFC.15 (MS); also elsewhere on the board
CSI_D7/LCD_D11: J-LCD-FFC.16 (MS); also elsewhere on the board
CSI_D8/LCD_D12: J-LCD-FFC.17 (MS); also elsewhere on the board
CSI_D9/LCD_D13: J-LCD-FFC.18 (MS); also elsewhere on the board
CSI_D10/LCD_D14: J-LCD-FFC.19 (MS); also elsewhere on the board
CSI_D11/LCD_D15: J-LCD-FFC.20 (MS); also elsewhere on the board
CSI_D12/LCD_D18: J-LCD-FFC.7 (MS); also elsewhere on the board
CSI_HSYNC/LCD_HSYNC: J-LCD-FFC.32 (MS); also elsewhere on the board
CSI_MCLK/LCD_DE: J-LCD-FFC.34 (MS); also elsewhere on the board
CSI_PCLK/LCD_CLK: J-LCD-FFC.30 (MS); also elsewhere on the board
CSI_VSYNC/LCD_VSYNC: J-LCD-FFC.33 (MS); also elsewhere on the board
EA-IN1: U$18.P$9 (9); also elsewhere on the board
EA-IN2: U$18.P$10 (10); also elsewhere on the board
GND: J-LCD-FFC.3 (MS), J-LCD-FFC.5 (MS), J-LCD-FFC.6 (MS), J-LCD-FFC.13 (MS), J-LCD-FFC.14 (MS), J-LCD-FFC.21 (MS), J-LCD-FFC.22 (MS), J-LCD-FFC.29 (MS), J-LCD-FFC.36 (MS), U$18.P$5 (5), U$18.P$6 (6); also elsewhere on the board
LCD_D19: J-LCD-FFC.8 (MS); also elsewhere on the board
LCD_D20: J-LCD-FFC.9 (MS); also elsewhere on the board
LCD_D21: J-LCD-FFC.10 (MS); also elsewhere on the board
LCD_D22: J-LCD-FFC.11 (MS); also elsewhere on the board
LCD_D23: J-LCD-FFC.12 (MS); also elsewhere on the board
TPX1: J-LCD-FFC.37 (MS), R43.2, U$2.1, U$18.P$1 (1); also elsewhere on the board
TPX2: J-LCD-FFC.39 (MS), U$2.3, U$18.P$3 (3); also elsewhere on the board
TPY1: J-LCD-FFC.38 (MS), R48.2, U$2.2, U$18.P$2 (2); also elsewhere on the board
TPY2: J-LCD-FFC.40 (MS), U$2.4, U$18.P$4 (4); also elsewhere on the board
VIB1: U$18.P$11 (11); also elsewhere on the board
VIB2: U$18.P$12 (12); also elsewhere on the board
VLED+: J-LCD-FFC.2 (MS), J-VLED.1; also elsewhere on the board
VLED-: J-VLED.2; also elsewhere on the board

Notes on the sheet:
LCD-FFC
Camera-FFC
LCD FFC / Camera FFC / Camera Header (OV7670, OV2640)

Board: 2 copper layers, 202 parts (107 on the bottom side), 204 nets, no tracks yet.

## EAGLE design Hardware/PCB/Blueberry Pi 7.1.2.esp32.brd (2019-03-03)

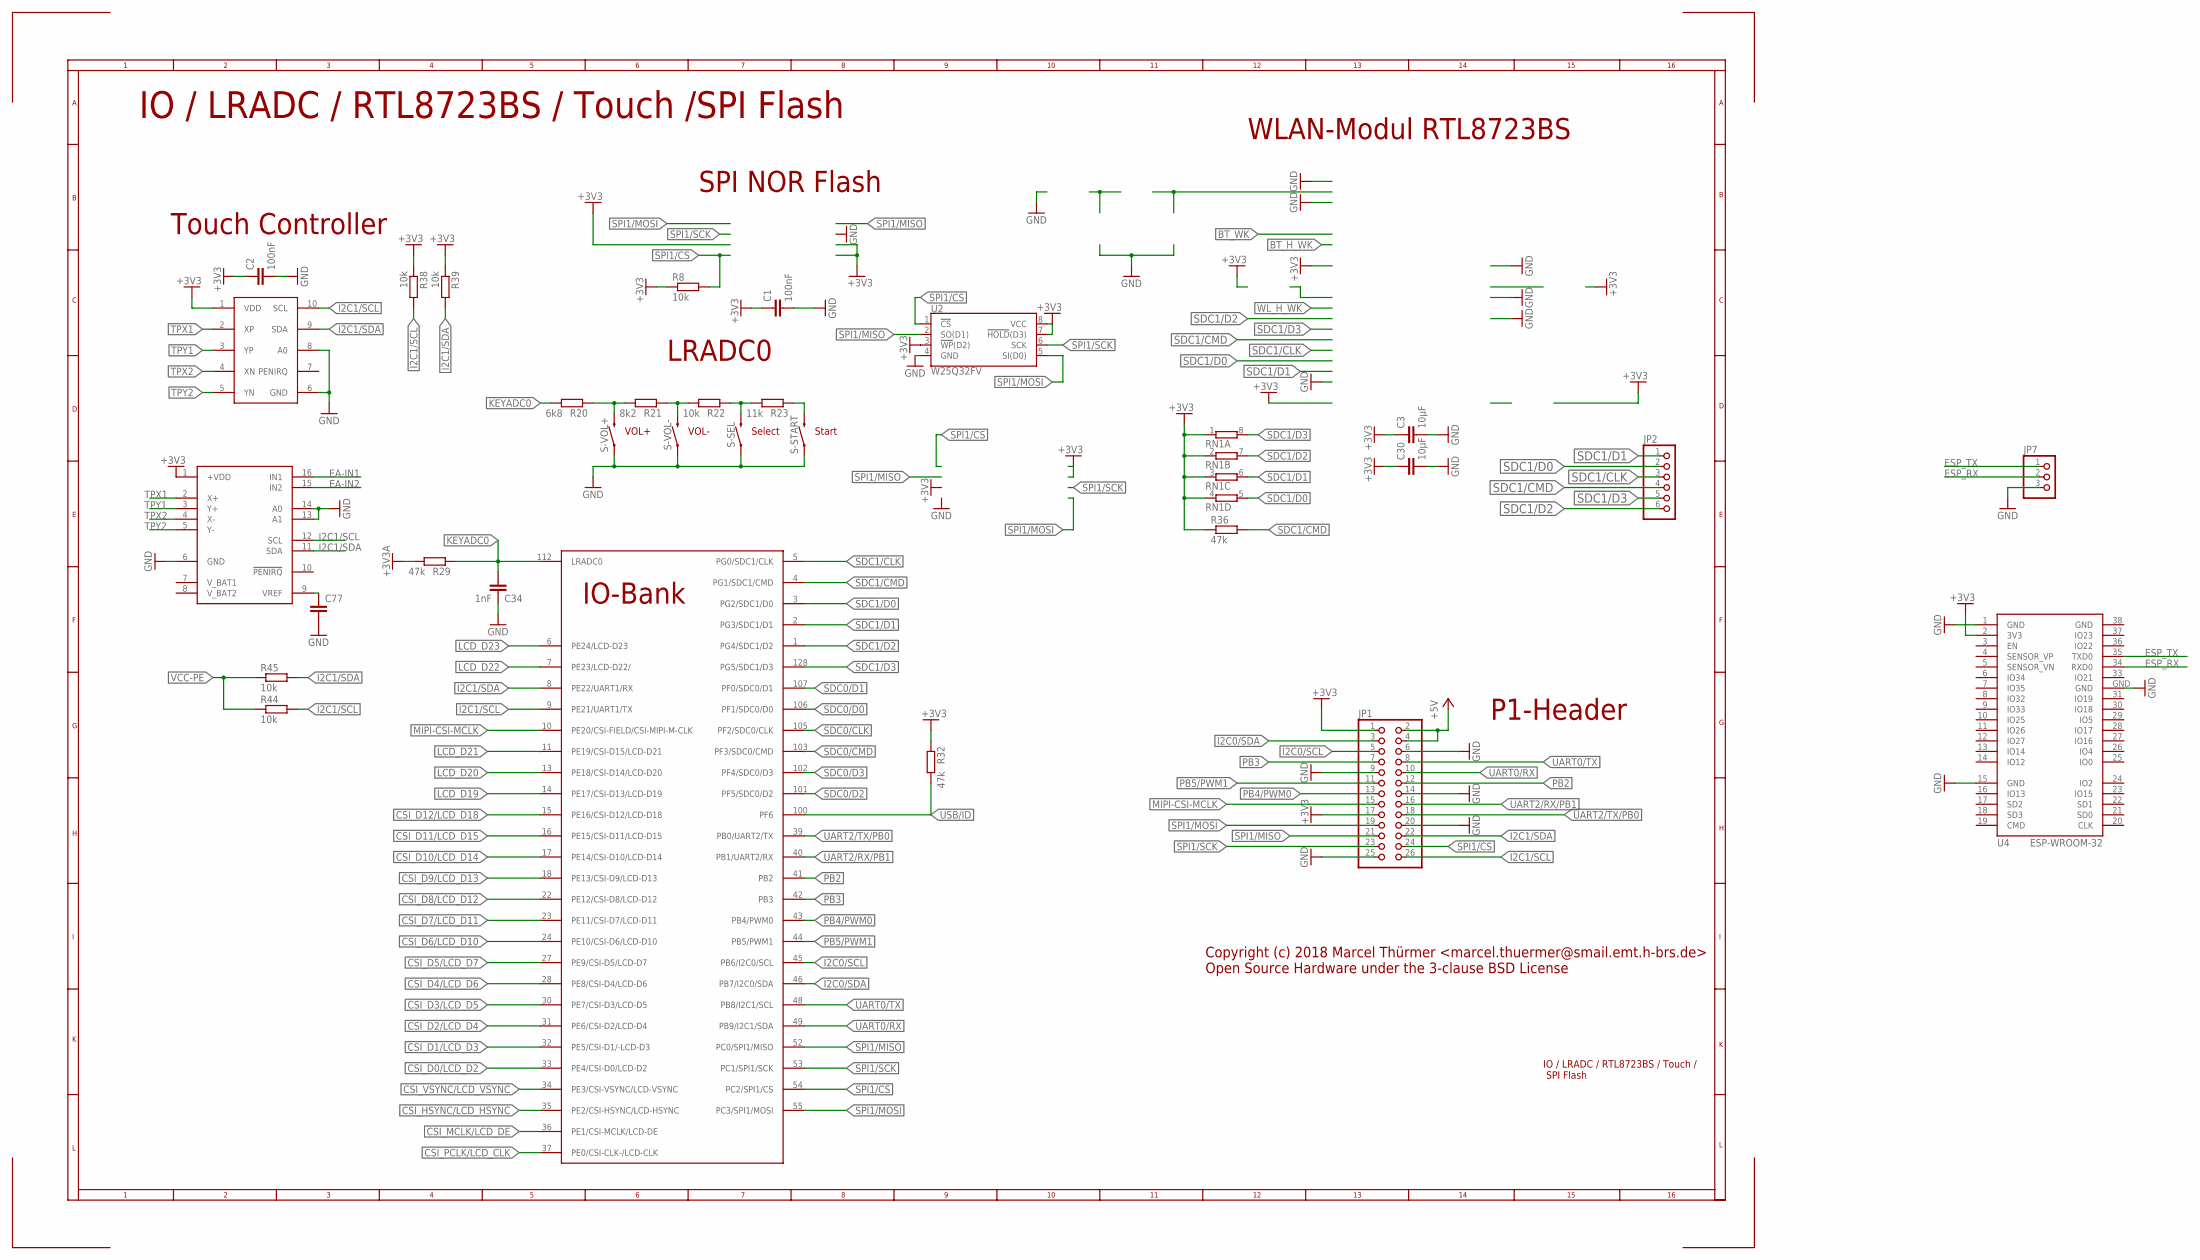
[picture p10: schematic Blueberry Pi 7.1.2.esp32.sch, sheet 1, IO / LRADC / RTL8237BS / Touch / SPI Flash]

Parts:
C1, C2: 100nF; C0603
C3, C30: 10µF; C0805
C34: 1nF; C0603
C77: C-EUC0805; C0805
JP1: PINHD-2X13; 2X13
JP2: PINHD-1X6_2.00; 1X06M
JP7: PINHD-1X3M; 1X03M
R8, R22, R38, R39, R44, R45: 10k; R0603
R20: 6k8; R0603
R21: 8k2; R0603
R23: 11k; R0603
R29, R32, R36: 47k; R0603
RN1: 4R-NEXB38V; EXB38V
S-SEL: SPARKFUN-SWITCHES_MOMENTARY-SWITCH-SPST-SMD-5.2-R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; SPARKFUN-SWITCHES_TACTILE_SWITCH_SMD_5.2MM
S-START: SPARKFUN-SWITCHES_MOMENTARY-SWITCH-SPST-SMD-5.2-R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; SPARKFUN-SWITCHES_TACTILE_SWITCH_SMD_5.2MM
S-VOL+: SPARKFUN-SWITCHES_MOMENTARY-SWITCH-SPST-SMD-5.2-R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; SPARKFUN-SWITCHES_TACTILE_SWITCH_SMD_5.2MM
S-VOL-: SPARKFUN-SWITCHES_MOMENTARY-SWITCH-SPST-SMD-5.2-R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; SPARKFUN-SWITCHES_TACTILE_SWITCH_SMD_5.2MM
U2: W25Q32FV; SOIC-8
U4: ESP-WROOM-32
U$1: V3S; QFP-128
U$7: TSC2003; TSSOP16
U$8: NS2009; MSOP10

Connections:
+3V3: C1.1, C2.1, C3.1, C30.1, JP1.1, JP1.17, R8.1, R32.1, R36.1, R38.1, R39.1, RN1.1, RN1.2 (1), RN1.3 (1), RN1.4 (1), U2.3 (!WP!(D2)), U2.7 (!HOLD!(D3)), U2.8 (VCC), U4.2 (3V3), U$7.1 (+VDD), U$8.1 (VDD); also elsewhere on the board
+3V3A: R29.2; also elsewhere on the board
+5V: JP1.2, JP1.4; also elsewhere on the board
CSI_D0/LCD_D2: U$1.33 (PE4/CSI-D0/LCD-D2); also elsewhere on the board
CSI_D1/LCD_D3: U$1.32 (PE5/CSI-D1/-LCD-D3); also elsewhere on the board
CSI_D2/LCD_D4: U$1.31 (PE6/CSI-D2/LCD-D4); also elsewhere on the board
CSI_D3/LCD_D5: U$1.30 (PE7/CSI-D3/LCD-D5); also elsewhere on the board
CSI_D4/LCD_D6: U$1.28 (PE8/CSI-D4/LCD-D6); also elsewhere on the board
CSI_D5/LCD_D7: U$1.27 (PE9/CSI-D5/LCD-D7); also elsewhere on the board
CSI_D6/LCD_D10: U$1.24 (PE10/CSI-D6/LCD-D10); also elsewhere on the board
CSI_D7/LCD_D11: U$1.23 (PE11/CSI-D7/LCD-D11); also elsewhere on the board
CSI_D8/LCD_D12: U$1.22 (PE12/CSI-D8/LCD-D12); also elsewhere on the board
CSI_D9/LCD_D13: U$1.18 (PE13/CSI-D9/LCD-D13); also elsewhere on the board
CSI_D10/LCD_D14: U$1.17 (PE14/CSI-D10/LCD-D14); also elsewhere on the board
CSI_D11/LCD_D15: U$1.16 (PE15/CSI-D11/LCD-D15); also elsewhere on the board
CSI_D12/LCD_D18: U$1.15 (PE16/CSI-D12/LCD-D18); also elsewhere on the board
CSI_HSYNC/LCD_HSYNC: U$1.35 (PE2/CSI-HSYNC/LCD-HSYNC); also elsewhere on the board
CSI_MCLK/LCD_DE: U$1.36 (PE1/CSI-MCLK/LCD-DE); also elsewhere on the board
CSI_PCLK/LCD_CLK: U$1.37 (PE0/CSI-CLK-/LCD-CLK); also elsewhere on the board
CSI_VSYNC/LCD_VSYNC: U$1.34 (PE3/CSI-VSYNC/LCD-VSYNC); also elsewhere on the board
EA-IN1: U$7.16 (IN1); also elsewhere on the board
EA-IN2: U$7.15 (IN2); also elsewhere on the board
ESP_RX: JP7.2, U4.34 (RXD0)
ESP_TX: JP7.1, U4.35 (TXD0)
GND: C1.2, C2.2, C3.2, C30.2, C34.1, C77.2, JP1.6, JP1.9, JP1.14, JP1.20, JP1.25, JP7.3, S-SEL.1, S-SEL.2 (1), S-START.1, S-START.2 (1), S-VOL+.1, S-VOL+.2 (1), S-VOL-.1, S-VOL-.2 (1), U2.4 (GND), U4.1 (GND), U4.15 (GND), U4.38 (GND), U4.GND, U$7.6 (GND), U$7.13 (A1), U$7.14 (A0), U$8.6 (GND), U$8.8 (A0); also elsewhere on the board
I2C0/SCL: JP1.5, U$1.45 (PB6/I2C0/SCL)
I2C0/SDA: JP1.3, U$1.46 (PB7/I2C0/SDA)
I2C1/SCL: JP1.26, R38.2, R44.2, U$1.9 (PE21/UART1/TX), U$7.12 (SCL), U$8.10 (SCL); also elsewhere on the board
I2C1/SDA: JP1.22, R39.2, R45.2, U$1.8 (PE22/UART1/RX), U$7.11 (SDA), U$8.9 (SDA); also elsewhere on the board
KEYADC0: C34.2, R20.2, R29.1, U$1.112 (LRADC0)
LCD_D19: U$1.14 (PE17/CSI-D13/LCD-D19); also elsewhere on the board
LCD_D20: U$1.13 (PE18/CSI-D14/LCD-D20); also elsewhere on the board
LCD_D21: U$1.11 (PE19/CSI-D15/LCD-D21); also elsewhere on the board
LCD_D22: U$1.7 (PE23/LCD-D22/); also elsewhere on the board
LCD_D23: U$1.6 (PE24/LCD-D23); also elsewhere on the board
MIPI-CSI-MCLK: JP1.15, U$1.10 (PE20/CSI-FIELD/CSI-MIPI-M-CLK); also elsewhere on the board
unnamed: R20.1, R21.2, S-VOL+.3 (2), S-VOL+.4 (2)
unnamed: C77.1, U$7.9 (VREF)
unnamed: R21.1, R22.2, S-VOL-.3 (2), S-VOL-.4 (2)
unnamed: R22.1, R23.2, S-SEL.3 (2), S-SEL.4 (2)
unnamed: R23.1, S-START.3 (2), S-START.4 (2)
PB2: JP1.12, U$1.41 (PB2); also elsewhere on the board
PB3: JP1.7, U$1.42 (PB3); also elsewhere on the board
PB4/PWM0: JP1.13, U$1.43 (PB4/PWM0)
PB5/PWM1: JP1.11, U$1.44 (PB5/PWM1)
SDC0/CLK: U$1.105 (PF2/SDC0/CLK); also elsewhere on the board
SDC0/CMD: U$1.103 (PF3/SDC0/CMD); also elsewhere on the board
SDC0/D0: U$1.106 (PF1/SDC0/D0); also elsewhere on the board
SDC0/D1: U$1.107 (PF0/SDC0/D1); also elsewhere on the board
SDC0/D2: U$1.101 (PF5/SDC0/D2); also elsewhere on the board
SDC0/D3: U$1.102 (PF4/SDC0/D3); also elsewhere on the board
SDC1/CLK: JP2.3, U$1.5 (PG0/SDC1/CLK)
SDC1/CMD: JP2.4, R36.2, U$1.4 (PG1/SDC1/CMD)
SDC1/D0: JP2.2, RN1.5 (2), U$1.3 (PG2/SDC1/D0)
SDC1/D1: JP2.1, RN1.6 (2), U$1.2 (PG3/SDC1/D1)
SDC1/D2: JP2.6, RN1.7 (2), U$1.1 (PG4/SDC1/D2)
SDC1/D3: JP2.5, RN1.8 (2), U$1.128 (PG5/SDC1/D3)
SPI1/CS: JP1.24, R8.2, U2.1 (!CS!), U$1.54 (PC2/SPI1/CS)
SPI1/MISO: JP1.21, U2.2 (SO(D1)), U$1.52 (PC0/SPI1/MISO)
SPI1/MOSI: JP1.19, U2.5 (SI(D0)), U$1.55 (PC3/SPI1/MOSI)
SPI1/SCK: JP1.23, U2.6 (SCK), U$1.53 (PC1/SPI1/SCK)
TPX1: U$7.2 (X+), U$8.2 (XP); also elsewhere on the board
TPX2: U$7.4 (X-), U$8.4 (XN); also elsewhere on the board
TPY1: U$7.3 (Y+), U$8.3 (YP); also elsewhere on the board
TPY2: U$7.5 (Y-), U$8.5 (YN); also elsewhere on the board
UART0/RX: JP1.10, U$1.49 (PB9/I2C1/SDA)
UART0/TX: JP1.8, U$1.48 (PB8/I2C1/SCL)
UART2/RX/PB1: JP1.16, U$1.40 (PB1/UART2/RX)
UART2/TX/PB0: JP1.18, U$1.39 (PB0/UART2/TX)
USB/ID: R32.2, U$1.100 (PF6); also elsewhere on the board
VCC-PE: R44.1, R45.1

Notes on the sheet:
IO / LRADC / RTL8723BS / Touch / SPI Flash
Copyright (c) 2018 Marcel Thürmer <marcel.thuermer@smail.emt.h-brs.de> Open Source Hardware under the 3-clause BSD License
SPI NOR Flash
WLAN-Modul RTL8723BS
P1-Header
LRADC0
Start
Select
VOL-
VOL+
Touch Controller
IO / LRADC / RTL8723BS / Touch /SPI Flash

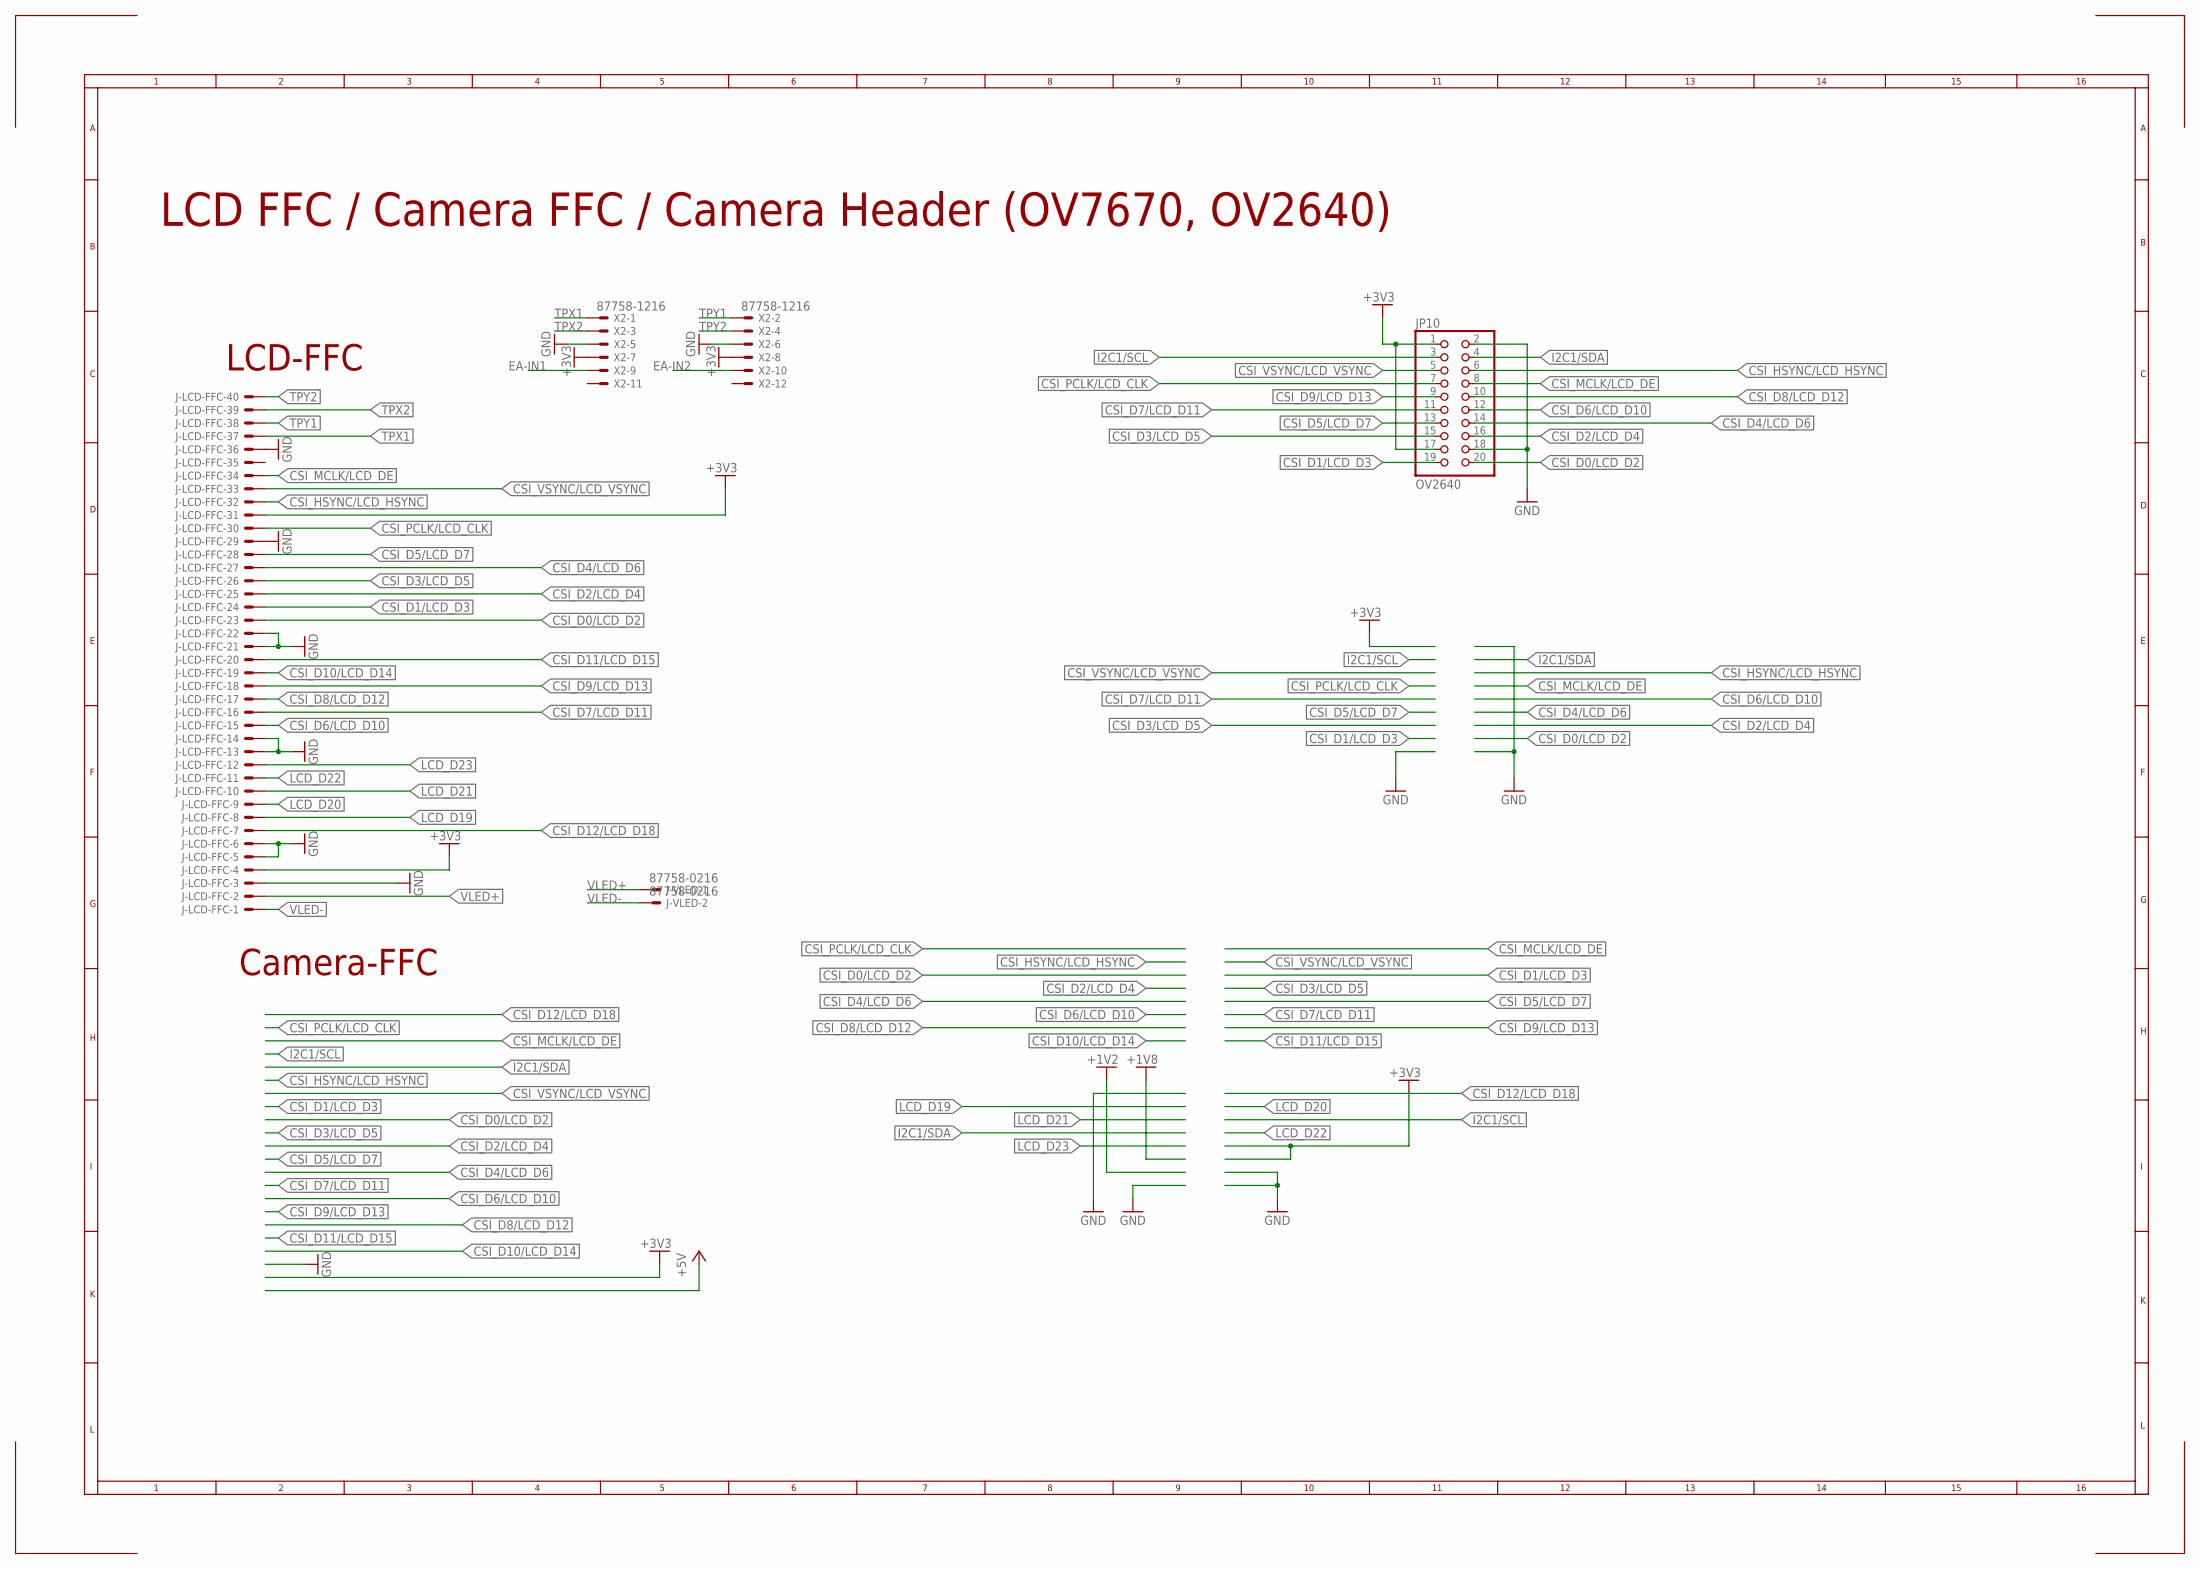
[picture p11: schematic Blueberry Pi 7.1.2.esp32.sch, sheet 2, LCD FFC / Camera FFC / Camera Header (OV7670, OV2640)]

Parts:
J-LCD-FFC: 40PINFPCH15-1LW; XF2H-4015-1LW
J-VLED: 87758-0216
JP10: OV2640; 2X10
X2: 87758-1216

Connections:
+3V3: J-LCD-FFC.4 (MS), J-LCD-FFC.31 (MS), JP10.1, JP10.17, X2.7, X2.8; also elsewhere on the board
CSI_D0/LCD_D2: J-LCD-FFC.23 (MS), JP10.20; also elsewhere on the board
CSI_D1/LCD_D3: J-LCD-FFC.24 (MS), JP10.19; also elsewhere on the board
CSI_D2/LCD_D4: J-LCD-FFC.25 (MS), JP10.16; also elsewhere on the board
CSI_D3/LCD_D5: J-LCD-FFC.26 (MS), JP10.15; also elsewhere on the board
CSI_D4/LCD_D6: J-LCD-FFC.27 (MS), JP10.14; also elsewhere on the board
CSI_D5/LCD_D7: J-LCD-FFC.28 (MS), JP10.13; also elsewhere on the board
CSI_D6/LCD_D10: J-LCD-FFC.15 (MS), JP10.12; also elsewhere on the board
CSI_D7/LCD_D11: J-LCD-FFC.16 (MS), JP10.11; also elsewhere on the board
CSI_D8/LCD_D12: J-LCD-FFC.17 (MS), JP10.10; also elsewhere on the board
CSI_D9/LCD_D13: J-LCD-FFC.18 (MS), JP10.9; also elsewhere on the board
CSI_D10/LCD_D14: J-LCD-FFC.19 (MS); also elsewhere on the board
CSI_D11/LCD_D15: J-LCD-FFC.20 (MS); also elsewhere on the board
CSI_D12/LCD_D18: J-LCD-FFC.7 (MS); also elsewhere on the board
CSI_HSYNC/LCD_HSYNC: J-LCD-FFC.32 (MS), JP10.6; also elsewhere on the board
CSI_MCLK/LCD_DE: J-LCD-FFC.34 (MS), JP10.8; also elsewhere on the board
CSI_PCLK/LCD_CLK: J-LCD-FFC.30 (MS), JP10.7; also elsewhere on the board
CSI_VSYNC/LCD_VSYNC: J-LCD-FFC.33 (MS), JP10.5; also elsewhere on the board
EA-IN1: X2.9; also elsewhere on the board
EA-IN2: X2.10; also elsewhere on the board
GND: J-LCD-FFC.3 (MS), J-LCD-FFC.5 (MS), J-LCD-FFC.6 (MS), J-LCD-FFC.13 (MS), J-LCD-FFC.14 (MS), J-LCD-FFC.21 (MS), J-LCD-FFC.22 (MS), J-LCD-FFC.29 (MS), J-LCD-FFC.36 (MS), JP10.2, JP10.18, X2.5, X2.6; also elsewhere on the board
I2C1/SCL: JP10.3; also elsewhere on the board
I2C1/SDA: JP10.4; also elsewhere on the board
LCD_D19: J-LCD-FFC.8 (MS); also elsewhere on the board
LCD_D20: J-LCD-FFC.9 (MS); also elsewhere on the board
LCD_D21: J-LCD-FFC.10 (MS); also elsewhere on the board
LCD_D22: J-LCD-FFC.11 (MS); also elsewhere on the board
LCD_D23: J-LCD-FFC.12 (MS); also elsewhere on the board
TPX1: J-LCD-FFC.37 (MS), X2.1; also elsewhere on the board
TPX2: J-LCD-FFC.39 (MS), X2.3; also elsewhere on the board
TPY1: J-LCD-FFC.38 (MS), X2.2; also elsewhere on the board
TPY2: J-LCD-FFC.40 (MS), X2.4; also elsewhere on the board
VLED+: J-LCD-FFC.2 (MS), J-VLED.1; also elsewhere on the board
VLED-: J-LCD-FFC.1 (MSV), J-VLED.2; also elsewhere on the board

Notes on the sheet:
LCD-FFC
Camera-FFC
LCD FFC / Camera FFC / Camera Header (OV7670, OV2640)

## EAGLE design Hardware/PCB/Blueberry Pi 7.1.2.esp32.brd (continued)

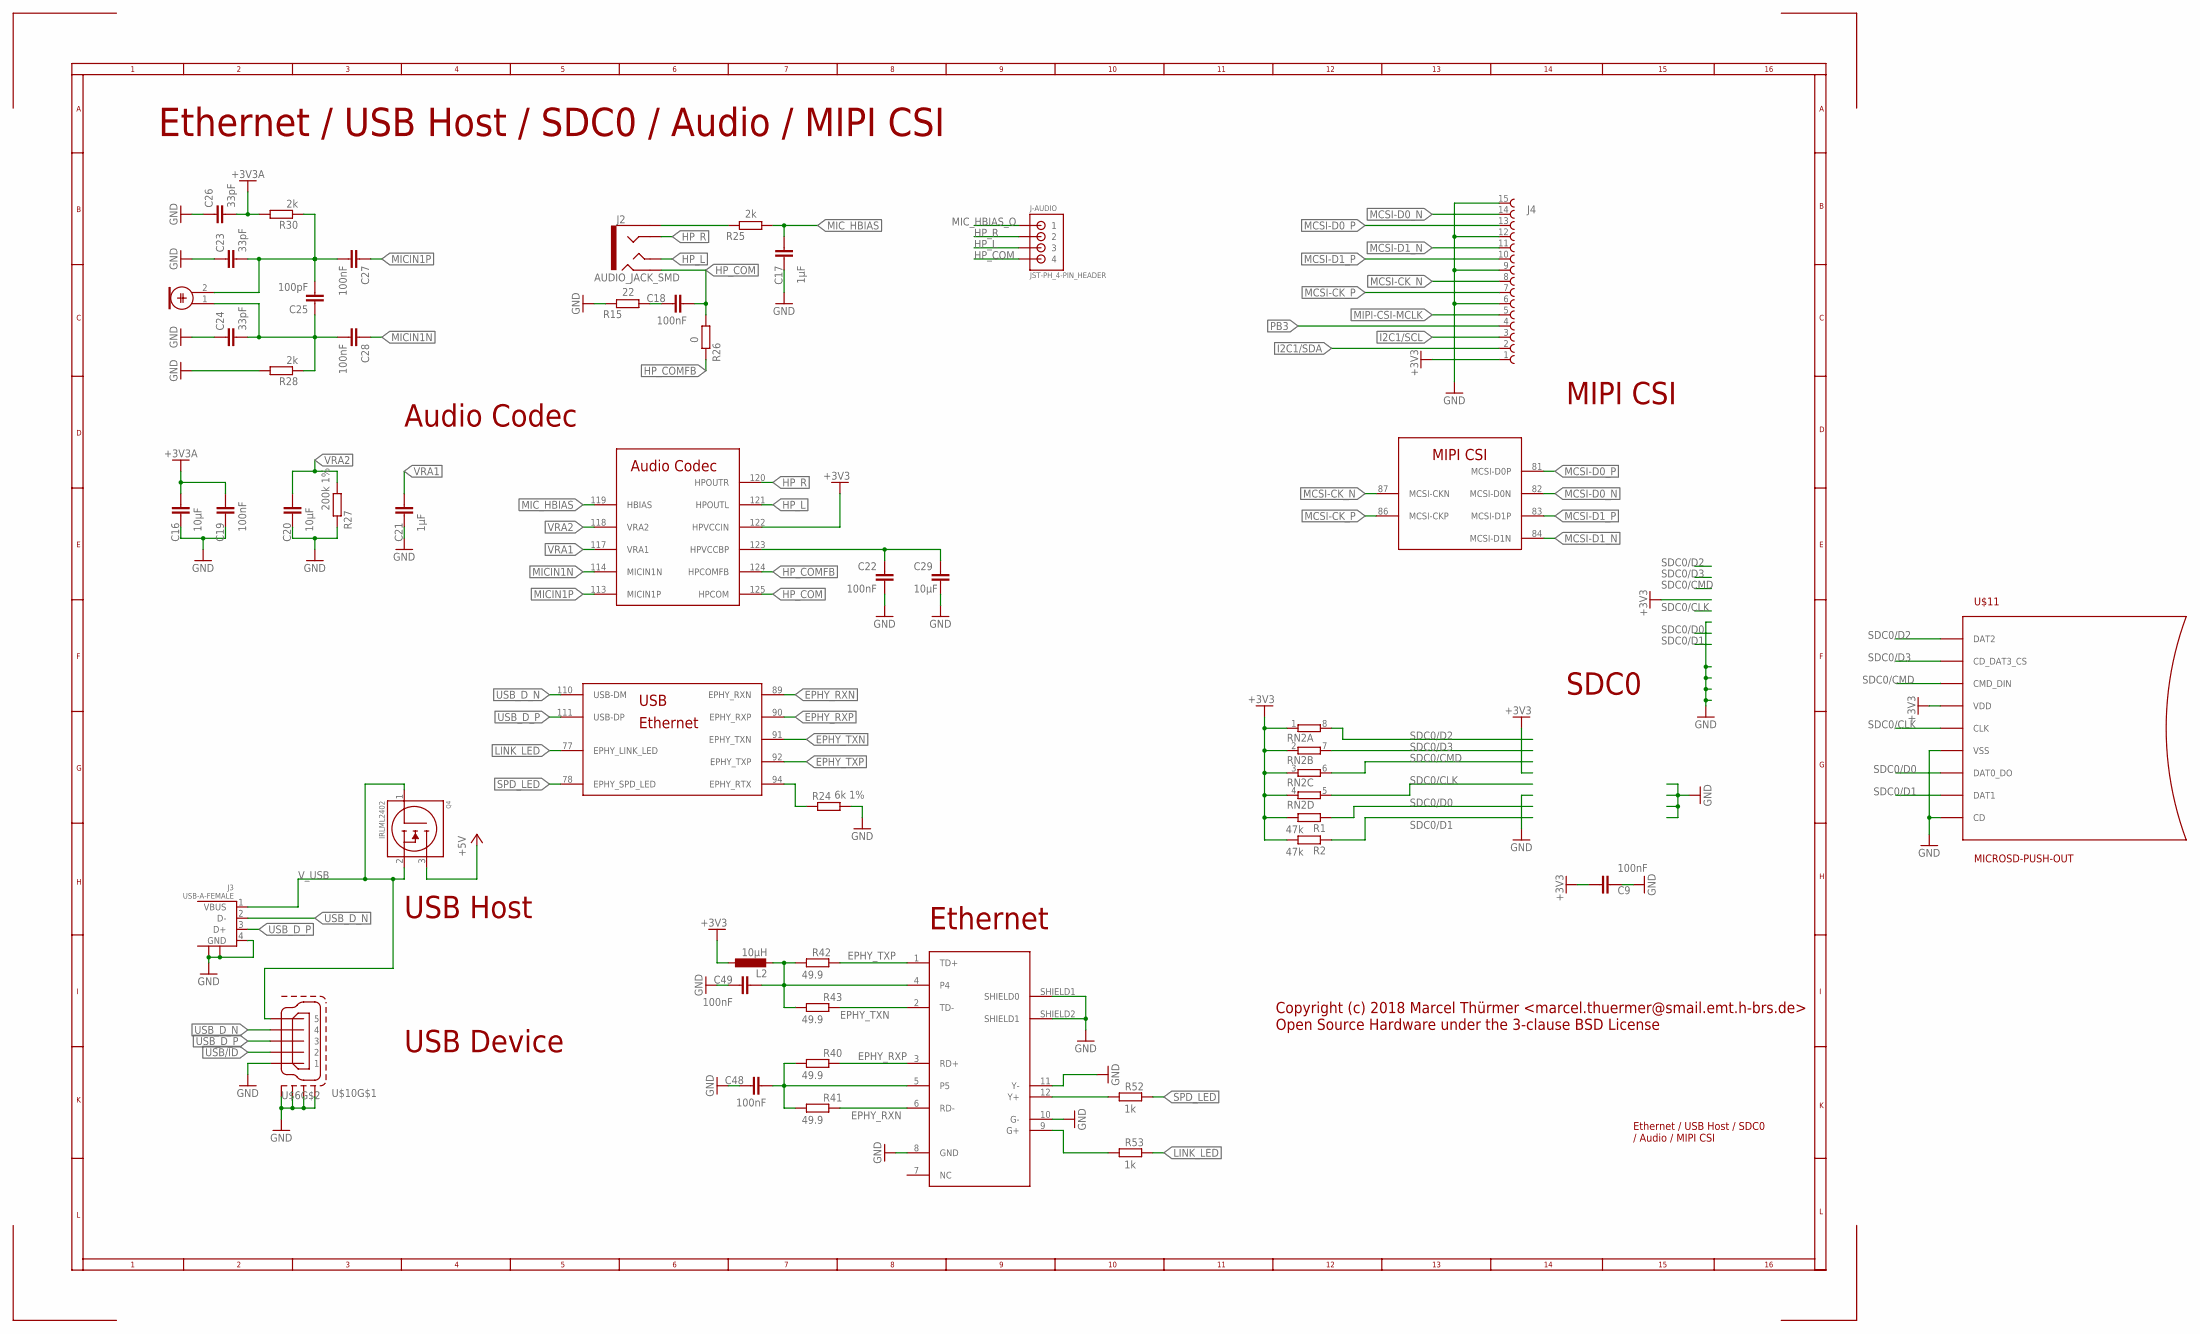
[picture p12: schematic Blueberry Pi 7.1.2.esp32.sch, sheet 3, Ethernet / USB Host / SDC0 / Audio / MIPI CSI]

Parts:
C9, C18, C19, C22, C27, C28, C48, C49: 100nF; C0603
C16, C20, C29: 10µF; C0805
C17, C21: 1µF; C0603
C23, C24, C26: 33pF; C0603
C25: 100pF; C0603
J2: AUDIO_JACK_SMD; AUDIO_JACK_3.5MM_TRRS_SMD_RA
J3: USB-A-FEMALE
J4: 68611514122
J-AUDIO: JST-PH_4-PIN_HEADER; JST_B4B-PH_HEADER
L2: 10µH; L0805
MIC: ELECTRET_MICROPHON-F6035AP; F6035AP
Q4: IRLML2402; SOT23
R1, R2: 47k; R0603
R15: 22; R0603
R24: 6k 1%; R0603
R25, R28, R30: 2k; R0603
R26: 0; R0603
R27: 200k 1%; R0603
R40, R41, R42, R43: 49.9; R0603
R52, R53: 1k; R0603
RN2: 4R-NEXB38V; EXB38V
U$1: V3S; QFP-128
U$3: HR911105A; RJ45
U$6, U$10: MICRO-USB-SHIELD-ZX62R-B-5P; ZX62R-B-5P
U$11: MICROSD-PUSH-OUT

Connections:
+3V3: C9.1, J4.1 (15), L2.1, R1.2, R2.2, RN2.1, RN2.2 (1), RN2.3 (1), RN2.4 (1), U$1.122 (HPVCCIN), U$11.4 (VDD); also elsewhere on the board
+3V3A: C16.2, C19.2, C26.2, R30.2; also elsewhere on the board
+5V: Q4.3 (DRAIN); also elsewhere on the board
EPHY_RXN: R41.1, U$1.89 (EPHY_RXN), U$3.6 (RD-)
EPHY_RXP: R40.1, U$1.90 (EPHY_RXP), U$3.3 (RD+)
EPHY_TXN: R43.1, U$1.91 (EPHY_TXN), U$3.2 (TD-)
EPHY_TXP: R42.1, U$1.92 (EPHY_TXP), U$3.1 (TD+)
GND: C9.2, C16.1, C17.2, C19.1, C20.1, C21.1, C22.2, C23.1, C24.1, C26.1, C29.1, C48.2, C49.2, J3.4 (GND), J3.P$1, J3.P$2, J4.6 (10), J4.9 (7), J4.12 (4), J4.15 (1), R15.1, R24.2, R27.1, R28.2, U$3.8 (GND), U$3.10 (G-), U$3.11 (Y-), U$3.SHIELD1 (SHIELD0), U$3.SHIELD2 (SHIELD1), U$6.1, U$10.M1 (S1), U$10.M2 (S2), U$10.M3 (S3), U$10.M4 (S4), U$11.6 (VSS), U$11.CD, U$11.G1 (VSS), U$11.G2 (VSS), U$11.G3 (VSS), U$11.G4 (VSS); also elsewhere on the board
HP_COM: C18.2, J2.RING2, J-AUDIO.P4 (4), R26.2, U$1.125 (HPCOM)
HP_COMFB: R26.1, U$1.124 (HPCOMFB)
HP_L: J2.TIP, J-AUDIO.P3 (3), U$1.121 (HPOUTL)
HP_R: J2.RING1, J-AUDIO.P2 (2), U$1.120 (HPOUTR)
I2C1/SCL: J4.3 (13); also elsewhere on the board
I2C1/SDA: J4.2 (14); also elsewhere on the board
LINK_LED: R53.1, U$1.77 (EPHY_LINK_LED)
MCSI-CK_N: J4.8, U$1.87 (MCSI-CKN)
MCSI-CK_P: J4.7 (9), U$1.86 (MCSI-CKP)
MCSI-D0_N: J4.14 (2), U$1.82 (MCSI-D0N)
MCSI-D0_P: J4.13 (3), U$1.81 (MCSI-D0P)
MCSI-D1_N: J4.11 (5), U$1.84 (MCSI-D1N)
MCSI-D1_P: J4.10 (6), U$1.83 (MCSI-D1P)
MICIN1N: C28.1, U$1.114 (MICIN1N)
MICIN1P: C27.1, U$1.113 (MICIN1P)
MIC_HBIAS: C17.1, R25.2, U$1.119 (HBIAS)
MIC_HBIAS_O: J2.EARTH, J-AUDIO.P1 (1), R25.1
MIPI-CSI-MCLK: J4.5 (11); also elsewhere on the board
unnamed: R24.1, U$1.94 (EPHY_RTX)
unnamed: R53.2, U$3.9 (G+)
unnamed: R52.2, U$3.12 (Y+)
unnamed: C49.1, L2.2, R42.2, R43.2, U$3.4
unnamed: C48.1, R40.2, R41.2, U$3.5
unnamed: C22.1, C29.2, U$1.123 (HPVCCBP)
unnamed: C18.1, R15.2
unnamed: C23.2, C25.2, C27.2, MIC.2, R30.1
unnamed: C24.2, C25.1, C28.2, MIC.1, R28.1
PB3: J4.4 (12); also elsewhere on the board
SDC0/CLK: RN2.5 (2), U$11.5 (CLK); also elsewhere on the board
SDC0/CMD: RN2.6 (2), U$11.3 (CMD_DIN); also elsewhere on the board
SDC0/D0: R1.1, U$11.7 (DAT0_DO); also elsewhere on the board
SDC0/D1: R2.1, U$11.8 (DAT1); also elsewhere on the board
SDC0/D2: RN2.8 (2), U$11.1 (DAT2); also elsewhere on the board
SDC0/D3: RN2.7 (2), U$11.2 (CD_DAT3_CS); also elsewhere on the board
SPD_LED: R52.1, U$1.78 (EPHY_SPD_LED)
USB/ID: U$6.2; also elsewhere on the board
USB_D_N: J3.2 (D-), U$1.110 (USB-DM), U$6.4
USB_D_P: J3.3 (D+), U$1.111 (USB-DP), U$6.3
VRA1: C21.2, U$1.117 (VRA1)
VRA2: C20.2, R27.2, U$1.118 (VRA2)
V_USB: J3.1 (VBUS), Q4.1 (GATE), Q4.2 (SOURCE), U$6.5

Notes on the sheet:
Ethernet / USB Host / SDC0 / Audio / MIPI CSI
USB Host
Audio Codec
MIPI CSI
Ethernet
SDC0
Copyright (c) 2018 Marcel Thürmer <marcel.thuermer@smail.emt.h-brs.de> Open Source Hardware under the 3-clause BSD License
USB Device
Ethernet / USB Host / SDC0 / Audio / MIPI CSI

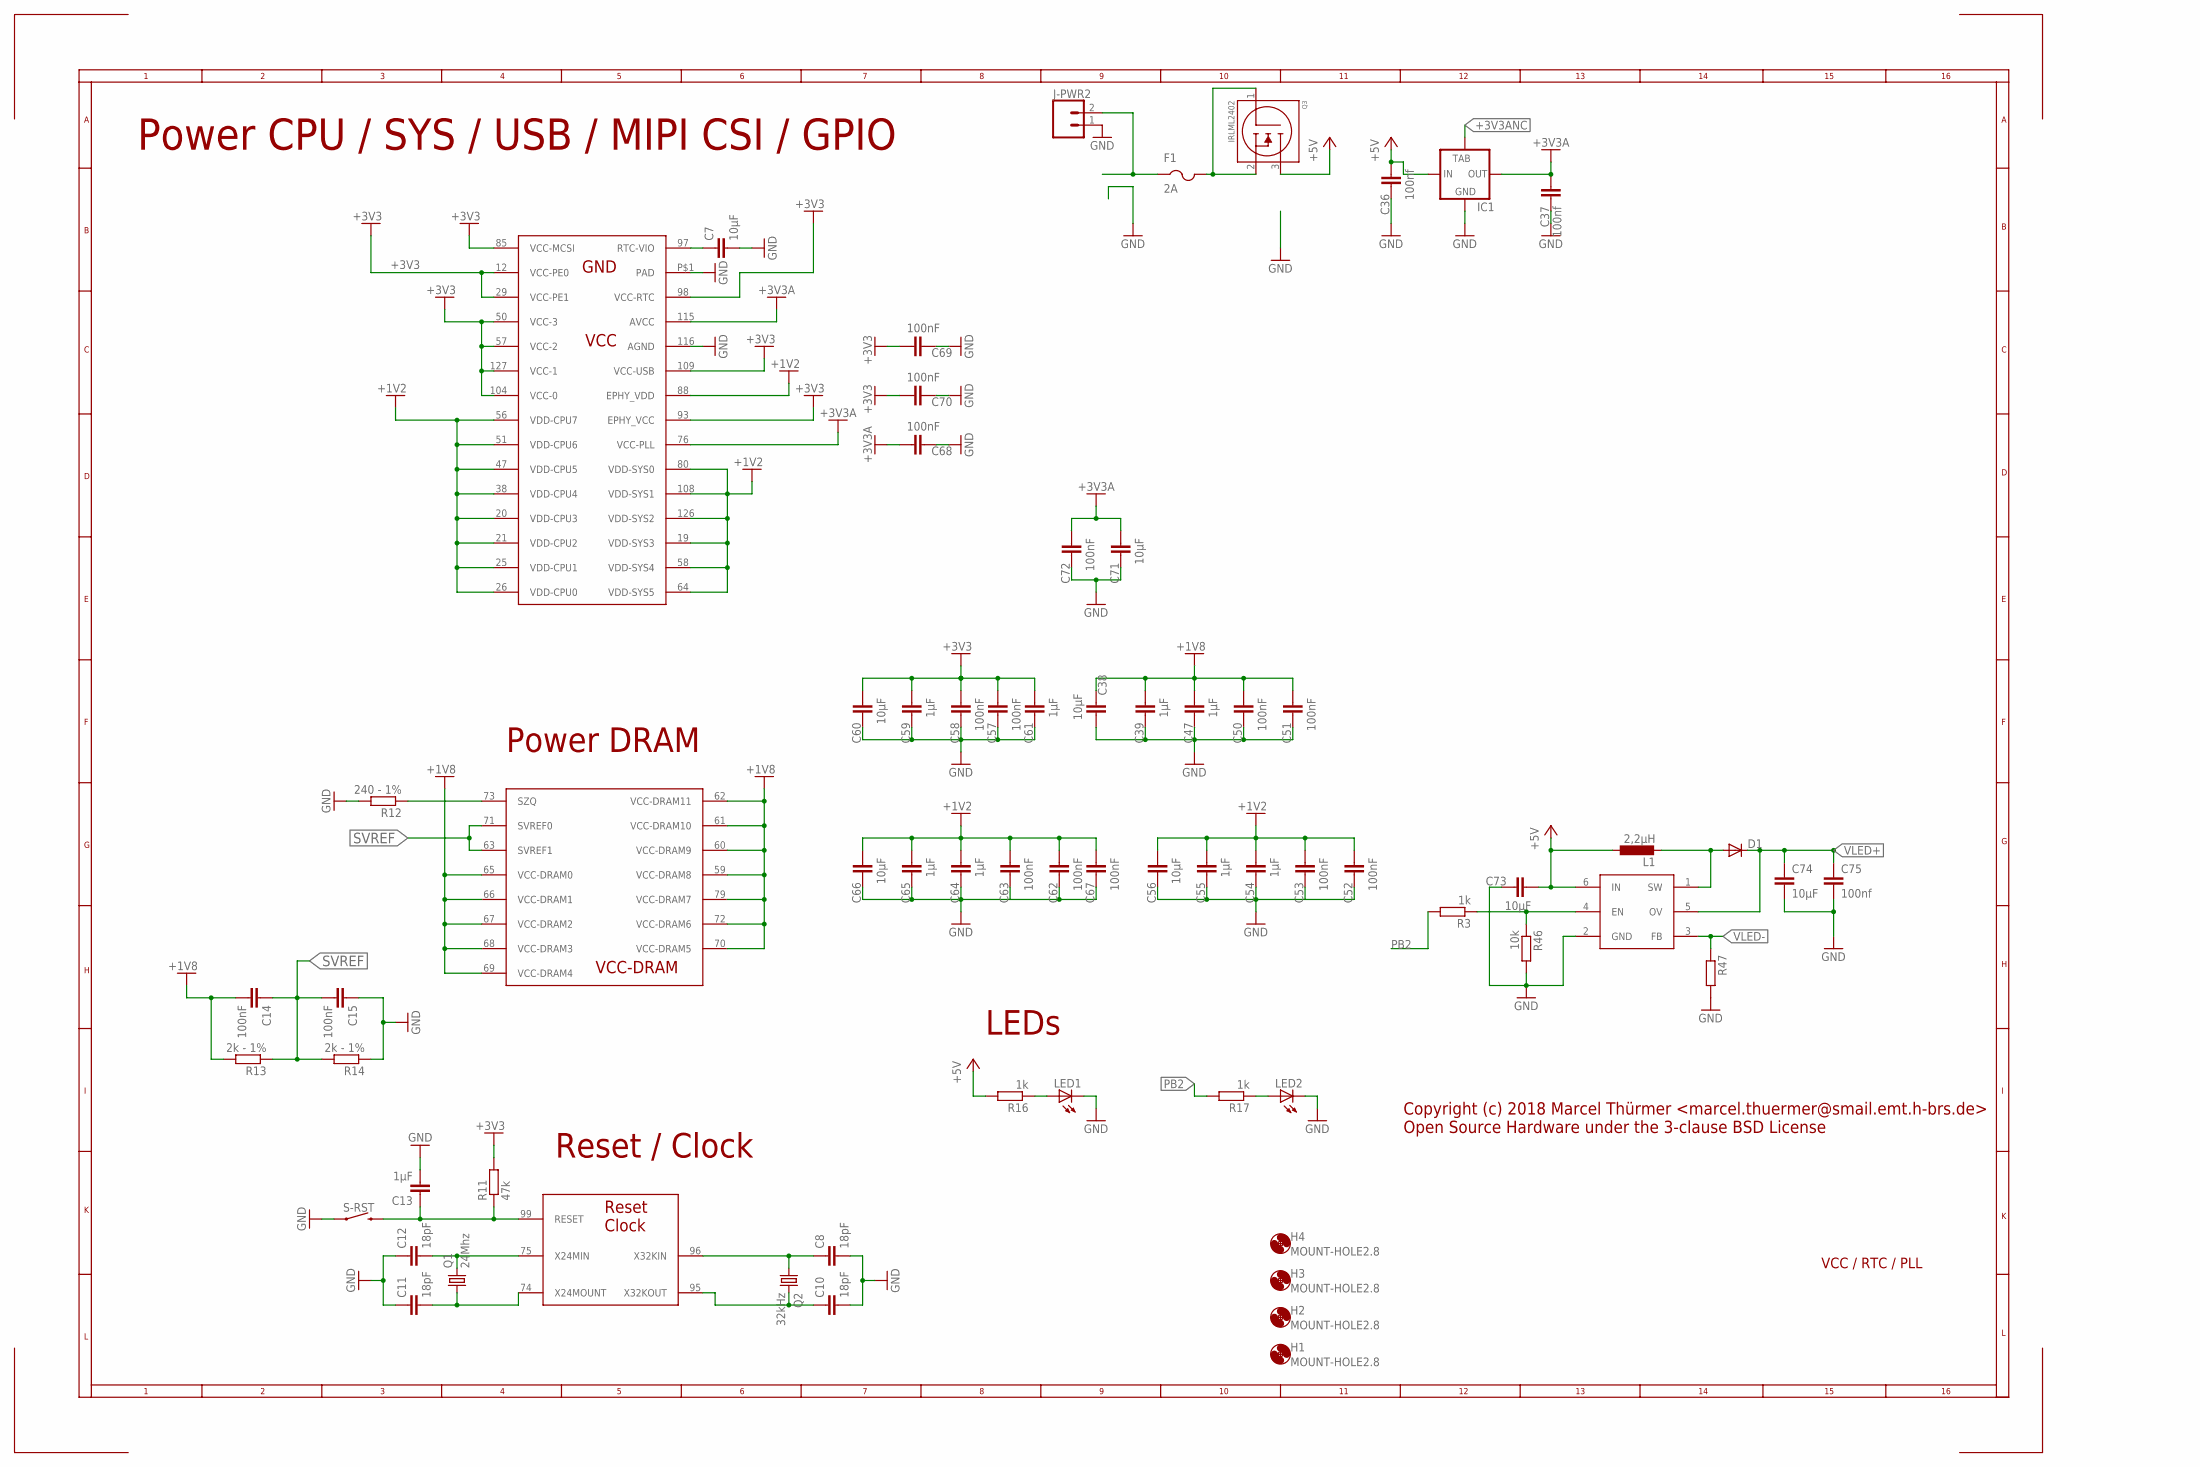
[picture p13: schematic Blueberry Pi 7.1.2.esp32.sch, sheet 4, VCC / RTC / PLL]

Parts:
C7, C66, C73, C74: 10µF; C0805
C8, C10, C11, C12: 18pF; C0603
C13, C39, C47, C55, C64, C65: 1µF; C0603
C14, C15, C51, C53, C57, C58, C62, C67, C68, C70, C72: 100nF; C0603
C36, C37, C75: 100nf; C0603
C38, C56, C60, C71: 10µF; C0603
C50, C52, C63, C69: 100nF; C0805
C54, C59, C61: 1µF; C0805
D1: DIODE-SOD323-W; SOD323-W
F1: 2A; R1206
H1, H2, H3, H4: MOUNT-HOLE2.8; 2,8
IC1: LM1117; SOT223
J-PWR2: CONN_02; 1X02
L1: 2,2µH; ODD-INDUCTOR
LED1, LED2: LEDCHIPLED_0805; CHIPLED_0805
Q1: 24Mhz; HC49U-V
Q2: 32kHz; TC38H
Q3: IRLML2402; SOT23
R3, R16, R17: 1k; R0603
R11: 47k; R0603
R12: 240 - 1%; R0603
R13, R14: 2k - 1%; R0603
R46: 10k; R0603
R47: R-EU_R0603; R0603
S-RST: SPARKFUN-SWITCHES_MOMENTARY-SWITCH-SPST-SMD-5.2-R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; SPARKFUN-SWITCHES_TACTILE_SWITCH_SMD_5.2MM
U$1: V3S; QFP-128
U$9: PT4101; SOT23-6

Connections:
5VNS: F1.1, J-PWR2.2
+1V2: C52.1, C53.1, C54.1, C55.1, C56.1, C62.1, C63.1, C64.1, C65.1, C66.1, C67.1, U$1.19 (VDD-SYS3), U$1.20 (VDD-CPU3), U$1.21 (VDD-CPU2), U$1.25 (VDD-CPU1), U$1.26 (VDD-CPU0), U$1.38 (VDD-CPU4), U$1.47 (VDD-CPU5), U$1.51 (VDD-CPU6), U$1.56 (VDD-CPU7), U$1.58 (VDD-SYS4), U$1.64 (VDD-SYS5), U$1.80 (VDD-SYS0), U$1.88 (EPHY_VDD), U$1.108 (VDD-SYS1), U$1.126 (VDD-SYS2); also elsewhere on the board
+1V8: C14.2, C38.2, C39.1, C47.1, C50.1, C51.1, R13.2, U$1.59 (VCC-DRAM8), U$1.60 (VCC-DRAM9), U$1.61 (VCC-DRAM10), U$1.62 (VCC-DRAM11), U$1.65 (VCC-DRAM0), U$1.66 (VCC-DRAM1), U$1.67 (VCC-DRAM2), U$1.68 (VCC-DRAM3), U$1.69 (VCC-DRAM4), U$1.70 (VCC-DRAM5), U$1.72 (VCC-DRAM6), U$1.79 (VCC-DRAM7); also elsewhere on the board
+3V3: C57.1, C58.1, C59.1, C60.1, C61.1, C69.1, C70.1, R11.2, U$1.12 (VCC-PE0), U$1.29 (VCC-PE1), U$1.50 (VCC-3), U$1.57 (VCC-2), U$1.85 (VCC-MCSI), U$1.93 (EPHY_VCC), U$1.98 (VCC-RTC), U$1.104 (VCC-0), U$1.109 (VCC-USB), U$1.127 (VCC-1); also elsewhere on the board
+3V3A: C37.1, C68.1, C71.1, C72.1, IC1.2 (OUT), U$1.76 (VCC-PLL), U$1.115 (AVCC); also elsewhere on the board
+3V3ANC: IC1.4 (IN1)
+5V: C36.1, C73.1, IC1.3 (IN), L1.P$1 (1), Q3.3 (DRAIN), R16.2, U$9.6 (IN); also elsewhere on the board
GND: C7.2, C8.2, C10.2, C11.1, C12.1, C13.2, C15.1, C36.2, C37.2, C38.1, C39.2, C47.2, C50.2, C51.2, C52.2, C53.2, C54.2, C55.2, C56.2, C57.2, C58.2, C59.2, C60.2, C61.2, C62.2, C63.2, C64.2, C65.2, C66.2, C67.2, C68.2, C69.2, C70.2, C71.2, C72.2, C73.2, C74.2, C75.2, IC1.1 (GND), J-PWR2.1, LED1.C, LED2.C, R12.2, R14.1, R46.2, R47.2, S-RST.1, S-RST.2 (1), U$1.116 (AGND), U$1.P$1 (PAD), U$9.2 (GND); also elsewhere on the board
unnamed: LED1.A, R16.1
unnamed: LED2.A, R17.1
unnamed: R3.1, R46.1, U$9.4 (EN)
unnamed: D1.A, L1.P$2 (2), U$9.1 (SW)
unnamed: C7.1, U$1.97 (RTC-VIO)
unnamed: C10.1, Q2.2, U$1.95 (X32KOUT)
unnamed: C8.1, Q2.1, U$1.96 (X32KIN)
unnamed: C11.2, Q1.1, U$1.74 (X24MOUNT)
unnamed: C12.2, Q1.2, U$1.75 (X24MIN)
unnamed: C13.1, R11.1, S-RST.3 (2), S-RST.4 (2), U$1.99 (RESET)
unnamed: R12.1, U$1.73 (SZQ)
PB2: R3.2, R17.2; also elsewhere on the board
SVREF: C14.1, C15.2, R13.1, R14.2, U$1.63 (SVREF1), U$1.71 (SVREF0)
VLED+: C74.1, C75.1, D1.C, U$9.5 (OV); also elsewhere on the board
VLED-: R47.1, U$9.3 (FB); also elsewhere on the board
V_PWR: F1.2, Q3.1 (GATE), Q3.2 (SOURCE)

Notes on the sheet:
VCC / RTC / PLL
Power CPU / SYS / USB / MIPI CSI / GPIO
Power DRAM
Copyright (c) 2018 Marcel Thürmer <marcel.thuermer@smail.emt.h-brs.de> Open Source Hardware under the 3-clause BSD License
Reset / Clock
LEDs


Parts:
J-LVDS: PINHEAD_PINHD-2X9M; PINHEAD_2X09M
U1: SN65LVDS84AQDGGRQ1; TFSOP-48-6.1MM

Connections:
+3V3: J-LVDS.1, J-LVDS.2, J-LVDS.3, U1.2 (VCC), U1.8 (VCC), U1.21 (VCC), U1.27 (!SHTDN), U1.29 (PLLVCC), U1.37 (LVDSVCC); also elsewhere on the board
CLK_N: J-LVDS.15, U1.33 (CLKOUT-)
CLK_P: J-LVDS.16, U1.32 (CLKOUT+)
CSI_D0/LCD_D2: U1.13 (D12); also elsewhere on the board
CSI_D1/LCD_D3: U1.15 (D13); also elsewhere on the board
CSI_D2/LCD_D4: U1.16 (D14); also elsewhere on the board
CSI_D3/LCD_D5: U1.18 (D15); also elsewhere on the board
CSI_D4/LCD_D6: U1.19 (D16); also elsewhere on the board
CSI_D5/LCD_D7: U1.20 (D17); also elsewhere on the board
CSI_D6/LCD_D10: U1.4 (D6); also elsewhere on the board
CSI_D7/LCD_D11: U1.6 (D7); also elsewhere on the board
CSI_D8/LCD_D12: U1.7 (D8); also elsewhere on the board
CSI_D9/LCD_D13: U1.9 (D9); also elsewhere on the board
CSI_D10/LCD_D14: U1.10 (D10); also elsewhere on the board
CSI_D11/LCD_D15: U1.12 (D11); also elsewhere on the board
CSI_D12/LCD_D18: U1.44 (D0); also elsewhere on the board
CSI_HSYNC/LCD_HSYNC: U1.22 (D18); also elsewhere on the board
CSI_MCLK/LCD_DE: U1.25 (D20); also elsewhere on the board
CSI_PCLK/LCD_CLK: U1.26 (CLKIN); also elsewhere on the board
CSI_VSYNC/LCD_VSYNC: U1.23 (D19); also elsewhere on the board
GND: J-LVDS.4, J-LVDS.5, J-LVDS.6, J-LVDS.13, J-LVDS.14, J-LVDS.17, J-LVDS.18, U1.5 (GND), U1.11 (GND), U1.17 (GND), U1.24 (GND), U1.28 (PLLGND), U1.30 (PLLGND), U1.31 (LVDSGND), U1.36 (LVDSGND), U1.42 (LVDSGND), U1.46 (GND); also elsewhere on the board
LCD_D19: U1.45 (D1); also elsewhere on the board
LCD_D20: U1.47 (D2); also elsewhere on the board
LCD_D21: U1.48 (D3); also elsewhere on the board
LCD_D22: U1.1 (D4); also elsewhere on the board
LCD_D23: U1.3 (D5); also elsewhere on the board
Y0_N: J-LVDS.7, U1.41 (Y0-)
Y0_P: J-LVDS.8, U1.40 (Y0+)
Y1_N: J-LVDS.9, U1.39 (Y1-)
Y1_P: J-LVDS.10, U1.38 (Y1+)
Y2_N: J-LVDS.11, U1.35 (Y2-)
Y2_P: J-LVDS.12, U1.34 (Y2+)


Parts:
C76, C79, C81, C83, C84, C85: 10µF; C0805
L6, L7, L8: 2,2µH; ODD-INDUCTOR
R4, R5, R33: 150k; R0603
R6: 200k; R0603
R18: 100k; R0603
R31: 680k; R0603
U$5, U$12, U$13: STI3411; SOT23-6

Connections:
+1V2: C76.2, L6.P$1 (1), R4.2; also elsewhere on the board
+1V8: C79.2, L7.P$1 (1), R6.2; also elsewhere on the board
+3V3: C81.2, L8.P$1 (1), R31.2; also elsewhere on the board
+5V: C83.2, C84.2, C85.2, U$5.1 (EN), U$5.4 (VIN), U$12.1 (EN), U$12.4 (VIN), U$13.1 (EN), U$13.4 (VIN); also elsewhere on the board
GND: C76.1, C79.1, C81.1, C83.1, C84.1, C85.1, R5.1, R18.1, R33.1, U$5.2 (GND), U$12.2 (GND), U$13.2 (GND); also elsewhere on the board
unnamed: L6.P$2 (2), U$13.3 (LX)
unnamed: L7.P$2 (2), U$5.3 (LX)
unnamed: R4.1, R5.2, U$13.6 (FB)
unnamed: L8.P$2 (2), U$12.3 (LX)
unnamed: R6.1, R18.2, U$5.6 (FB)
unnamed: R31.1, R33.2, U$12.6 (FB)

Board: 2 copper layers, 163 parts (94 on the bottom side), 137 nets, no tracks yet.

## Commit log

2018-09-03 added LVDS serialiser SN65LVDS84
    [Blueberry Pi 7.1.brd, Blueberry Pi 7.1.sch, out-7.1.brd]
2018-09-03 w25q128, tsc2003, TF slot. README
2018-09-04 a PCB with AXP203 power was added (without EA3036). may be powered from a Li-battery
    [Blueberry Pi 7.1+axp203.brd, Blueberry Pi 7.1+axp203.sch, out-7.1+axp203.brd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]
2018-09-12 tracing of BBPi*AXP203 was upbated
    [out-7.1+axp203.brd]
2019-03-03 better power driwers, ESP32 as a WiFi/BLE controller, list of LCDs
    [Blueberry Pi 7.1.2.esp32.brd, Blueberry Pi 7.1.2.esp32.sch]
2019-03-13 added Blueberry Pi 7.1.2.esp32.no-lan. see Readme.md
    [Blueberry Pi 7.1.2.esp32.no-lan.brd, Blueberry Pi 7.1.2.esp32.no-lan.sch]
2019-03-17 added onboard li-ion/polimer battery charger, and step-up circuits for power from a li-battery.
    [Blueberry Pi 7.1.2.esp32.no-lan.brd, Blueberry Pi 7.1.2.esp32.no-lan.sch]
2019-03-20 added capacitive touch socket (not ready yet), other pwr-inductors (CD32), datasheets
    [Blueberry Pi 7.1.2.esp32.no-lan.brd, Blueberry Pi 7.1.2.esp32.no-lan.sch]
2019-03-28 interrupt pin for all touchscreens is PB3 shared with MIPI-CSI cam. basically added SPI-NOR-FLASH in the 16pins package (>= 32MB flashes)
    [Blueberry Pi 7.1.2.esp32.no-lan.brd, Blueberry Pi 7.1.2.esp32.no-lan.sch]
2019-04-01 photo of working framebuffer + touchscreen was added (inferno-os on the photo)
2019-04-08 (not finished yet) checks and new choise with SIM800C gsm module
    [Blueberry Pi 7.1.2.esp32.no-lan.brd, Blueberry Pi 7.1.2.esp32.no-lan.gsm-sim800c.brd, Blueberry Pi 7.1.2.esp32.no-lan.gsm-sim800c.sch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]
2019-04-25 switched to `A9G` as a GSM/GPRS/GPS/GNSS module. for now "Blueberry Pi 7.1.2.esp32.no-lan.gsm-a9g" is the main branch. small changes in power and touchscreen sockets
    [Blueberry Pi 7.1.2.esp32.no-lan.gsm-a9g.brd, Blueberry Pi 7.1.2.esp32.no-lan.gsm-a9g.sch]
2019-06-29 better connected A9G module. added 'no-50pin lcd' schematic easier for router and with headers for the rest of A9G pins
    [Blueberry Pi 7.1.2.esp32.no-lan.gsm-a9g.no-50p.brd, Blueberry Pi 7.1.2.esp32.no-lan.gsm-a9g.no-50p.sch]

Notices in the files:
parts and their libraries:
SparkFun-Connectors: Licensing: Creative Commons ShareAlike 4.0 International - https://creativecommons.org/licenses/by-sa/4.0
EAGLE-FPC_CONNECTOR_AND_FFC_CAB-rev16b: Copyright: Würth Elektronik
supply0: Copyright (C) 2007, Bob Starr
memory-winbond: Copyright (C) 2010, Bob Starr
